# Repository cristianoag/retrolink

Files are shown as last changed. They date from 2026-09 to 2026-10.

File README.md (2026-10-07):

# The Retro Hacker RetroLink

RetroLink is an open-source hardware and firmware project for connecting controllers to classic MSX computers through the MSX DB9 General Purpose port. **RetroLink USB** connects USB HID joysticks and gamepads, or USB mice when flashed with the mouse firmware. **RetroLink MD** translates Mega Drive/Genesis 3-button and 6-button controller signals into MSX joystick signals. Both variants use an RP2040 Zero.

### RetroLink USB

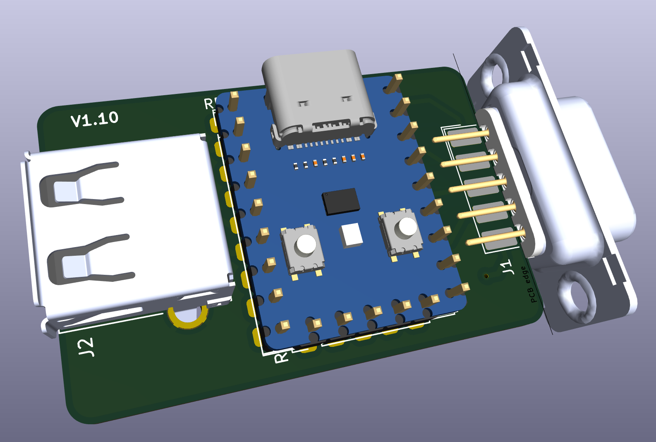
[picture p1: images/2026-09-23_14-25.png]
RetroLink USB hardware revision 1.10 angled 3D render with RP2040 Zero, USB-A connector, and DE9 socket


The latest RetroLink USB hardware revision, `1.10`, uses an RP2040 Zero module on a custom adapter board with:

- USB-A host connector for the USB HID device.
- DB9 connector for the MSX joystick/general purpose port.
- MSX DB9 pin 5 as the installed adapter power source.
- 1N5819 Schottky diode protection to prevent USB-C programming power from backfeeding the MSX.

### RetroLink MD

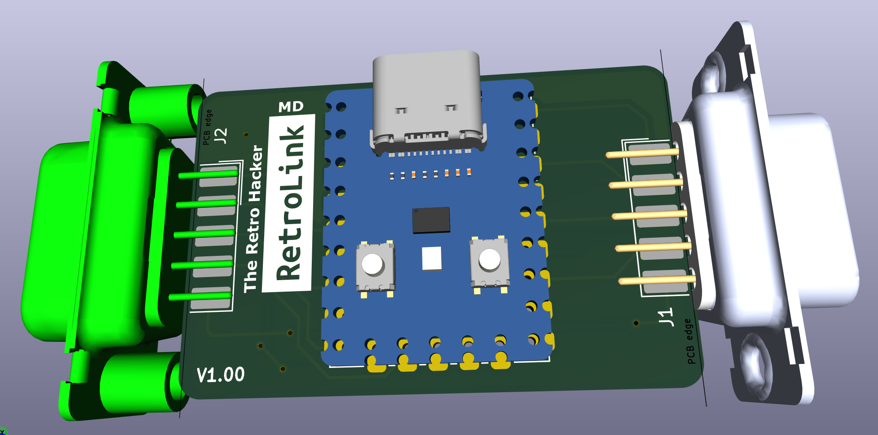
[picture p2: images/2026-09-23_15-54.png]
RetroLink MD revision 1.00 angled 3D render with RP2040 Zero and Mega Drive and MSX DE9 connectors


RetroLink MD hardware revision `1.10` replaces USB-A controller input with a **male DE9 for the Mega Drive controller**, retaining a **female DE9 for the MSX**. Its separate firmware maps MD B/C to MSX triggers A/B and reads the MSX common signal. 

## PCB Preview

### RetroLink USB revision 1.10

Top view of RetroLink USB hardware revision `1.10` (3D render):

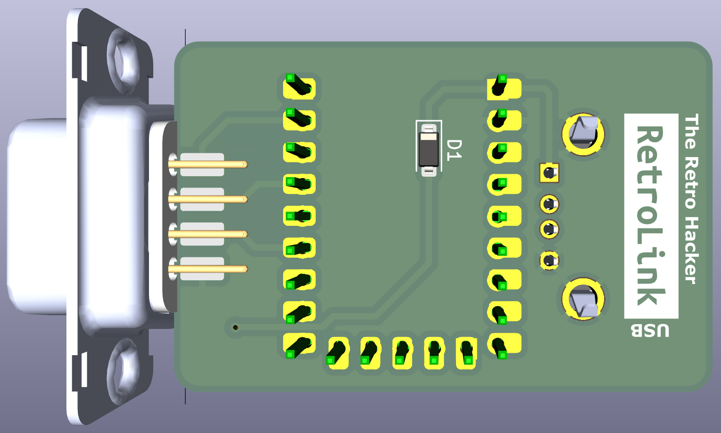
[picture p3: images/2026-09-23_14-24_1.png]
RetroLink USB revision 1.10 PCB top render with RP2040 Zero, USB-A connector, and DE9 socket


Bottom view of RetroLink USB hardware revision `1.10` (3D render):

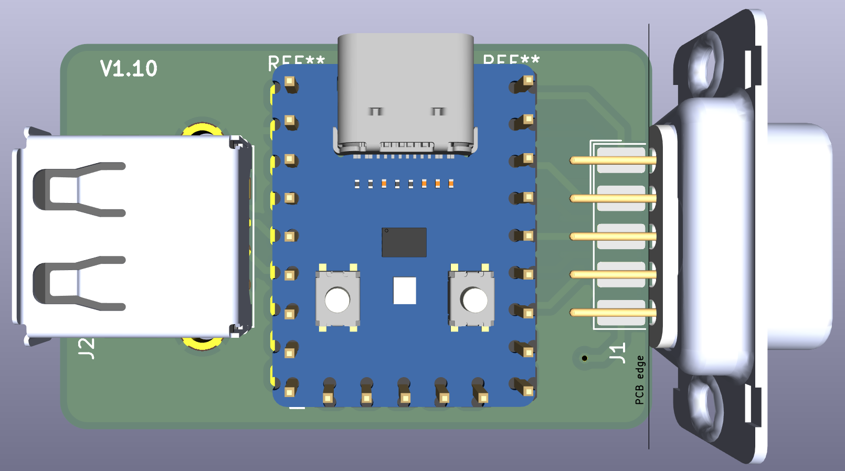
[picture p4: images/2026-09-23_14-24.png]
RetroLink USB revision 1.10 PCB bottom render showing the diode, connector pads, and RetroLink USB branding


### RetroLink MD revision 1.00

Front of the MD PCB (3D render):

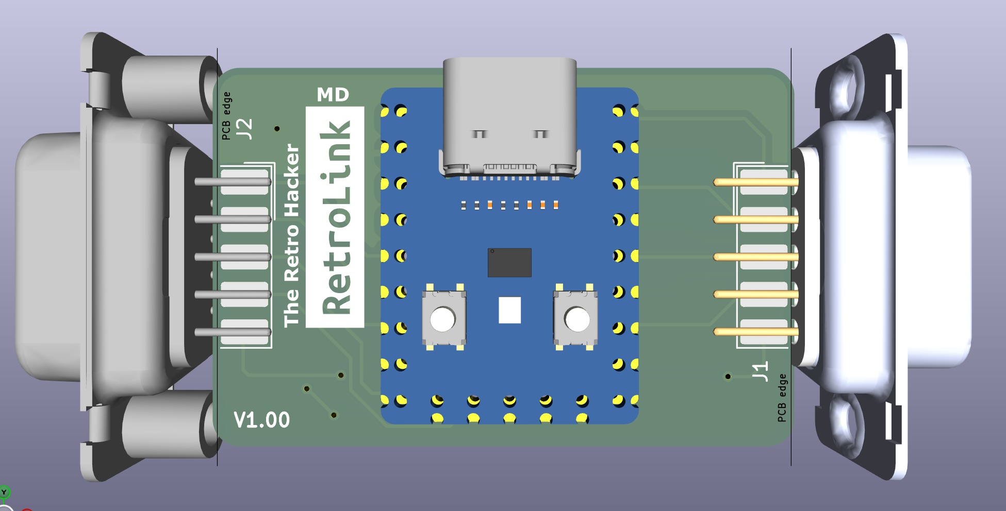
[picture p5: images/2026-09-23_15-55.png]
RetroLink MD revision 1.00 front render showing RP2040 Zero and both DE9 connectors


Back of the MD PCB (3D render):

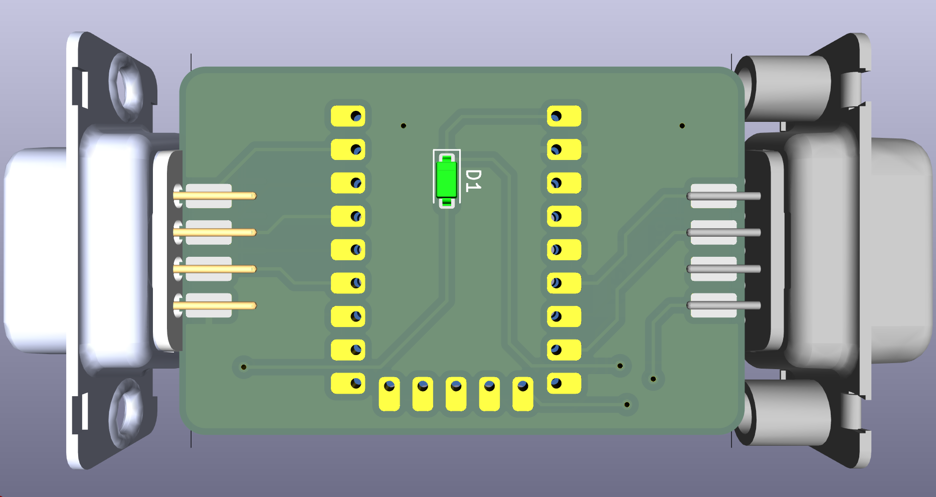
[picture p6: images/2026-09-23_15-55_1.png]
RetroLink MD revision 1.00 back render showing the diode, connector pads, and routing


## Variants and Versions

| Variant | Input | Hardware | Software and firmware |
| --- | --- | --- | --- |
| RetroLink USB | USB HID joystick/gamepad, or USB HID mouse | Latest: [revision `1.10`](hardware/usb/1.10); earlier revisions under [hardware/usb](hardware/usb) | [Joystick source](software/usb/joystick) (firmware `1.10`), [mouse source](software/usb/mouse) (firmware `1.00`), and [UF2 artifacts](firmware/usb) |
| RetroLink MD | Mega Drive/Genesis 3-/6-button controller | [Revision `1.10`](hardware/md/1.10) | [MD source](software/md) and [UF2 artifacts](firmware/md); firmware `1.10` |

The [USB specification](docs/specification.md) is version `1.00` and describes USB hardware revision `1.00`, not the MD variant. See the [MD wiring and behavior guide](software/md/README.md) for MD details and [docs/log.md](docs/log.md) for both variants' change log. Revisions are organized within each variant; a hardware directory does not imply a corresponding firmware release.

## Repository Layout

| Path | Purpose |
| --- | --- |
| [software/usb/joystick](software/usb/joystick) | USB joystick/gamepad firmware source using the Raspberry Pi Pico SDK, TinyUSB, and Pico-PIO-USB; also hosts sources shared with the mouse and MD builds. |
| [software/usb/mouse](software/usb/mouse) | USB mouse-to-MSX mouse firmware source for the same USB hardware. |
| [firmware/usb](firmware/usb) | USB joystick and mouse UF2 firmware artifacts. |
| [hardware/usb](hardware/usb) | USB KiCad project files by hardware revision. |
| [software/md](software/md), [firmware/md](firmware/md), [hardware/md](hardware/md) | MD controller-to-MSX source, generated UF2 firmware, and hardware revisions. |
| [images](images) | PCB preview renders used in this README. |
| [docs](docs) | Technical specification and version log. |
| [software/third_party/Pico-PIO-USB](software/third_party/Pico-PIO-USB) | Git submodule for GPIO-based USB host support on RP2040. |

## Firmware Build

### USB firmware

Initialize submodules after cloning:

```powershell
git submodule update --init --recursive
```

Build from the firmware source folder for the device you will connect:

```powershell
cd software\usb\joystick   # USB joysticks/gamepads
make
cd ..\mouse                # USB mice
make
```

Each build generates a versioned UF2 file for the same USB hardware:

```text
firmware/usb/retrolink-joystick-1.10.uf2
firmware/usb/retrolink-mouse-1.00.uf2
```

On Windows, the Makefile discovers Pico SDK-managed tools under `%USERPROFILE%\.pico-sdk`. Override `PICO_SDK_ROOT`, `PICO_SDK_PATH`, `PICO_TOOLCHAIN_PATH`, `CMAKE`, `CMAKE_MAKE_PROGRAM`, `PYTHON3_EXECUTABLE`, `PICOTOOL_DIR`, `PIOASM_DIR`, or `PICO_PIO_USB_PATH` if your toolchain is installed elsewhere.

### MD firmware

From the repository root, using the same Pico SDK toolchain:

```powershell
make -C software\md
```

Output: [firmware/md/retrolink-md-1.00.uf2](firmware/md/retrolink-md-1.00.uf2). The MD build does not use Pico-PIO-USB. See [MD build instructions and tests](software/md/README.md#build). Use the UF2 for the correct hardware variant.

## RetroLink MD Firmware Behavior

The controller data pins are **MD_UP=GPIO28, MD_BA=GPIO27, MD_DOWN=GPIO26, MD_THSEL=GPIO15, MD_LEFT=GPIO14, MD_CSTART=GPIO13, MD_RIGHT=GPIO12**. MSX up/A/down/B/left/common/right remain on GPIO0/1/2/3/4/5/6.

Firmware `1.10` reads standard 3- and 6-button pads, maps directions and B/C to the six MSX controls, and cancels opposing directions. A/Start/X/Y/Z/Mode are decoded but unmapped. Absent, invalid, or over-time frames release controls; reconnecting restores normal polling. GPIO5 monitors MSX OUT/common and releases all outputs when high. USB-C CDC provides diagnostics and GPIO16 LED pulses indicate newly asserted controls.

The MD [schematic](hardware/md/1.00/retrolink.kicad_sch), [PCB](hardware/md/1.00/retrolink.kicad_pcb), and [BOM](hardware/md/1.00/production/bom.csv) are available. MD pin 8 is ground, while MSX ground is pin 9 and MSX pin 8 is a driven signal. 

MD [revision `1.10`](hardware/md/1.10) also has a [dual-DB9 four-clip PLA case](hardware/md/1.10/case/README.md), measuring 54.19 x 33.50 x 19.70 mm after a 4 mm extension toward the male connector, with mirrored DB9 end profiles. Physical case fit and retention testing remain pending, particularly at the male end whose supplied 3D model is incorrect.

The MD build disables the RP2040 B0/B1 USB enumeration workaround because it takes over GPIO15 (MD SELECT); B2 silicon is preferred for USB-C diagnostics.

## RetroLink USB Joystick Firmware Behavior

USB joystick firmware version `1.10` (`retrolink-joystick-1.10.uf2`) decodes standard USB HID joystick/gamepad axes, hats, and buttons into six active-low MSX outputs: GPIO0/2/4/6 for up/down/left/right, GPIO1 for button A, and GPIO3 for button B. GPIO5 is reserved for the MSX OUT/strobe input, unused in joystick mode. Button usages 1 and 2 map to A and B. Outputs release to high impedance when inactive. The current source requires updated MSX wiring and USB-A D+/D- on GPIO27/28, not the original hardware revision `1.00` wiring. USB-C CDC provides diagnostics, and the RP2040 Zero status LED pulses on newly asserted controls. See [software/usb/joystick/README.md](software/usb/joystick/README.md#current-behavior) for supported layouts, decoder limits, and tests; physical controller/MSX validation remains required.

## RetroLink USB Mouse Firmware Behavior

USB mouse firmware version `1.00` (`retrolink-mouse-1.00.uf2`) runs on the same USB hardware revision `1.10`. It implements the MSX mouse protocol: each DB9 pin 8 (GPIO5) strobe edge places the next nibble of the signed X/Y movement on pins 1-4 (GPIO0/2/4/6). The left and right buttons drive pins 6/7 (GPIO1/3). A dedicated RP2040 core answers strobe edges in well under a microsecond. Boot-protocol and report-descriptor mice are supported, including report IDs and 12/16-bit axes. Holding the left button while connecting the mouse selects MSX-mouse-style joystick emulation. See [software/usb/mouse/README.md](software/usb/mouse/README.md#current-behavior) for protocol timing, scaling, limits, and tests; validation with a physical MSX remains required.

The current status LED implementation assumes the common RP2040 Zero onboard WS2812-compatible LED on GPIO 16. Validate this against the exact board variant before treating the build as hardware-final.

## RetroLink USB Hardware Status

The latest hardware revision, `1.10`, includes the KiCad project, schematic, PCB layout shown in the previews above, and updated BOM and production exports:

- [hardware/usb/1.10/retrolink.kicad_pro](hardware/usb/1.10/retrolink.kicad_pro)
- [hardware/usb/1.10/retrolink.kicad_sch](hardware/usb/1.10/retrolink.kicad_sch)
- [hardware/usb/1.10/retrolink.kicad_pcb](hardware/usb/1.10/retrolink.kicad_pcb)
- [The Retro Hacker RetroLink USB BOM (interactive, revision `1.10`)](hardware/usb/1.10/bom/ibom.html)
- [Exported component BOM](hardware/usb/1.10/production/bom.csv)
- [Production outputs](hardware/usb/1.10/production)
- [Compact four-clip PLA case: STLs, STEP and print instructions](hardware/usb/1.10/case/README.md) (reinforced short roots and padded DB9 rear support; physical strength and retention testing pending).

GitHub displays the iBOM HTML as a repository file, not an interactive page. Download the raw HTML or open the local file in a browser to use its component highlighting and assembly checklist.

## PCB Components

Quantities are per USB PCB, taken from the revision `1.10` [interactive BOM](hardware/usb/1.10/bom/ibom.html), dated 2026-09-23, and matching [production BOM](hardware/usb/1.10/production/bom.csv). AliExpress links are search placeholders, not verified product recommendations; replace them with selected listings after checking dimensions, pinout, package, and electrical ratings. Availability and seller quality have not been verified.

| Reference | Component / BOM value | Quantity | PCB footprint / selection notes | AliExpress |
| --- | --- | --- | --- | --- |
| RZ1 | RP2040 Zero module | 1 | `RP2040-Zero`; check module dimensions and pinout against the PCB. | [Search RP2040 Zero](https://www.aliexpress.com/w/wholesale-rp2040-zero.html) |
| J1 | DE9 female socket (`DE9_Socket`) | 1 | `DSUB-9_Socket_EdgeMount_P2.77mm`; edge-mount, 2.77 mm pitch. Verify contact gender and mounting geometry. | [Search DB9 female edge-mount](https://www.aliexpress.com/w/wholesale-db9-female-edge-mount.html) |
| J2 | USB-A receptacle (`USB_A`) | 1 | `TE_6364372-2`; verify signal pins, shell tabs, and mounting dimensions. | [Search USB-A PCB socket](https://www.aliexpress.com/w/wholesale-usb-type-a-female-pcb.html) |
| D1 | Schottky diode (`1N5819` BOM value) | 1 | `D_SOD-123`; the selected part must fit SOD-123. A common axial DO-41 1N5819 will not fit; confirm the exact SMD part, ratings, and polarity before ordering. | [Search 1N5819 SOD-123](https://www.aliexpress.com/w/wholesale-1n5819-sod-123.html) |

This table matches the revision `1.10` BOM exports; it does not establish electrical validation or a complete implementation of the specification's protection requirements. Use the iBOM for placement, and regenerate assembly outputs after hardware changes.

## License

This project is licensed under the [Creative Commons Attribution-NonCommercial-ShareAlike 4.0 International License](http://creativecommons.org/licenses/by-nc-sa/4.0/).

- You may remix and adapt the material with proper attribution.
- Derivative works must be shared under the same license.
- Commercial use is not permitted without explicit authorization.

See [LICENSE.txt](LICENSE.txt) for the full license text. Third-party components retain their respective licenses.

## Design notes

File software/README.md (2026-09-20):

# RetroLink Software

Firmware source code lives under this directory. Generated UF2 files are copied to `../firmware/` by the CMake build.

## Build

Prerequisites:

- Raspberry Pi Pico SDK available through `PICO_SDK_PATH`.
- A Pico SDK version that provides TinyUSB host support for RP2040 and, for hardware revision `1.00`, PIO USB host support on GPIO 2 and GPIO 3.
- Pico-PIO-USB providing `pio_usb.h` and the `pico_pio_usb` CMake target; the Makefile defaults to the repo submodule at `../third_party/Pico-PIO-USB`.
- CMake and an ARM GCC toolchain supported by the Pico SDK.

Build from this directory:

```powershell
make
```

On this development machine, the Makefile defaults to the Pico SDK-managed CMake, Ninja, Python, SDK, ARM GCC toolchain, picotool, and pioasm paths under `C:/Users/Cristiano/.pico-sdk`. Pico-PIO-USB is repo-managed under `../third_party/Pico-PIO-USB`. Override `CMAKE`, `CMAKE_MAKE_PROGRAM`, `PYTHON3_EXECUTABLE`, `PICO_SDK_PATH`, `PICO_TOOLCHAIN_PATH`, `PICOTOOL_DIR`, `PIOASM_DIR`, or `PICO_PIO_USB_PATH` on the `make` command line if another installation should be used.

After cloning the repository, initialize dependencies with:

```powershell
git submodule update --init --recursive
```

Or configure and build from the repository root:

```powershell
cmake -S software -B software/build -DPICO_SDK_PATH=$env:PICO_SDK_PATH
cmake --build software/build
```

The expected firmware artifact is:

```text
firmware/retrolink-1.00.uf2
```

The Makefile uses the same CMake target and keeps the firmware version in the UF2 file name.

## Current Behavior

Firmware version `1.00` initializes USB CDC debug on the RP2040 Zero USB-C port and TinyUSB host mode on the USB-A port through Pico-PIO-USB. Standard HID joystick/gamepad report descriptors determine the control locations; the first report is decoded immediately, not used as a neutral baseline.

| MSX control | GPIO | DB9 pin | USB HID control |
| --- | --- | --- | --- |
| Up | 6 | 1 | Low Y, hat up, or D-pad up |
| Down | 7 | 2 | High Y, hat down, or D-pad down |
| Left | 8 | 3 | Low X, hat left, or D-pad left |
| Right | 9 | 4 | High X, hat right, or D-pad right |
| Button A | 10 | 6 | Button usage 1 |
| Button B | 11 | 7 | Button usage 2 |

All outputs assert low and release to input/high impedance, with internal pull-ups disabled. The documented BSS138 level shifters and external pull-ups remain required; never connect 5 V MSX signals directly to RP2040 GPIOs. GPIO12 / DB9 pin 8 is not driven by this joystick implementation.

Absolute X/Y axes use the descriptor's logical range: below 25% asserts left/up, above 75% asserts right/down, and the middle 50% is neutral. Four-way and eight-way hats are supported, including diagonal combinations for eight-way hats; values outside the logical range are neutral. Axis and D-pad directions are combined. Opposing directions cancel each other. Button usage numbers may not match the controller's printed labels.

States are kept separately per report ID and interface and combined for the MSX port. Detach, truncated reports, and failed receive requests release the affected interface's contribution without releasing another controller's held controls. A failed receive request is logged; reconnect the controller to restart reception. Unknown report IDs leave the current state unchanged. The LED pulses on newly asserted decoded controls.

The decoder supports absolute variable fields in Joystick/Game Pad application collections, signed/unsigned fields up to 32 bits, and report IDs. It uses fixed limits: 32 mapped fields, 8 input report IDs, 512 input payload bits per report, 32 explicit local usages, 8 collection levels, and 4 global push levels. Oversized or unsupported descriptors are logged as `supported=0` and do not drive outputs. Array controls, relative axes, vendor-specific protocols, local delimiters, and long descriptor items are not supported; unsupported fields are ignored when other usable controls exist. Mouse emulation is not implemented. These limits and mappings have not yet been validated against the user's physical controller.

Use a serial terminal on the USB-C CDC device to monitor boot, host initialization, HID mount/unmount, descriptor mapping status, receive failures, and decoded state changes. The state byte uses bits 0 through 5 for up, down, left, right, A, and B respectively.

The status LED implementation assumes the common RP2040 Zero onboard WS2812-compatible LED on GPIO 16. If a board variant uses a different LED circuit, update `include/retrolink/board_config.h` before building.

## Module Interfaces

- `joystick_state_t` is a bitmask of the six `JOYSTICK_*` controls, independent of GPIO assignments.
- `hid_joystick_parse()` initializes a descriptor mapping and returns false with an empty mapping for unsupported or malformed descriptors.
- `hid_joystick_decode()` updates the matching report state and returns the combined state; false indicates an invalid report and clears all states for that interface. Unknown IDs are ignored successfully. Pass a parsed mapping and a non-null output state pointer.
- `msx_port_init()` releases all six GPIOs; `msx_port_set_state()` applies a complete logical state and cancels opposing directions. The trigger-A setter/getter remain available and preserve the other controls.

## Host Tests

After a firmware build has created `software/build`, run from the repository root with a native GCC compiler:

```powershell
gcc -std=c11 -Wall -Wextra -Werror -I software/include software/src/hid_joystick.c software/tests/hid_joystick_test.c -o software/build/hid_joystick_test.exe
./software/build/hid_joystick_test.exe
gcc -std=c11 -Wall -Wextra -Werror -I software/tests/stubs -I software/include software/src/msx_port.c software/tests/msx_port_test.c -o software/build/msx_port_test.exe
./software/build/msx_port_test.exe
```

Tests cover descriptor bounds, report IDs, axes, hats, buttons, GPIO assignments, high-impedance release, held-control continuity, and opposing directions. GPIO tests use a stub; they do not establish electrical or USB runtime correctness. On hardware, verify each direction and button, simultaneous controls, neutral release, and unplugging while controls are held.

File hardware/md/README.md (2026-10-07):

# RetroLink MD Hardware

RetroLink MD revision [1.00](1.00/) connects a Mega Drive controller's female DE9 plug to a male DE9 on the adapter; the adapter's female DE9 connects to the MSX. An RP2040 Zero translates the controller protocol into MSX joystick signals.

- [Schematic](1.00/retrolink.kicad_sch)
- [PCB](1.00/retrolink.kicad_pcb)
- [Project](1.00/retrolink.kicad_pro)
- [Exported BOM](1.00/production/bom.csv)
- [Renders](../../README.md#retrolink-md-revision-100)
- [Firmware, exact GPIO assignments, and electrical prerequisites](../../software/md/README.md)

MD D0/D1/D2/D3/D4/D5 use GPIO28/26/14/12/27/13; TH/SELECT uses GPIO15. MSX up/A/down/B/left/common/right use GPIO0/1/2/3/4/5/6. GPIO16 is the status LED. No USB-A host or MSX voltage-sense input is assigned in this variant.

USB hardware is maintained separately under [hardware/usb](../usb/).

Revision [1.10](1.10/) has a [compact four-clip PLA case](1.10/case/README.md)
for its two DB9 connectors, with STLs, STEP and a parametric generator. Its
54.19 x 33.50 x 19.70 mm plastic envelope is extended 4 mm toward the male DB9
relative to the original USB-sized design. The male end mirrors the female-end
profile instead of using the known incorrect male 3D model's through-passages.
USB-C programming requires opening the case. Physical fit,
clip durability and connector retention still require testing.

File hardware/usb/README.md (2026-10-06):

# RetroLink USB Hardware

KiCad hardware revisions for the USB HID-to-MSX variant live here. Revision `1.00` has the PCB and production exports documented in the [project README](../../README.md#retrolink-usb-hardware-status). Revision `1.10` is present as a separate revision directory; check its project files before using it for fabrication. The planned Mega Drive-to-MSX design belongs in [hardware/md](../md/), not here.

Revision `1.10` also has a [compact four-clip PLA case](1.10/case/README.md), with printable STLs, an editable STEP assembly, and a parametric generator. It exposes USB-A and DB9; opening the case is required for RP2040 Zero USB-C programming. Dedicated PCB end stops target 0.20 mm total nominal lengthwise play. Reinforced short clip roots and a padded metal-backshell cradle keep the DB9 flange outside. No screws or long latches are used; physical clip strength and frictional connector retention still require testing.

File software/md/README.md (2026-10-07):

# RetroLink MD Software

RP2040 Zero firmware `1.10` for RetroLink MD hardware revision `1.10`; its GPIO assignments also match revision `1.00`. It polls standard Mega Drive/Genesis 3-button and 6-button controllers and translates directions plus B/C into MSX joystick signals. This is a separate build from [RetroLink USB](../usb/README.md); do not flash a USB joystick or mouse UF2 onto the MD board.

## Wiring

### Mega Drive connector (male DE9)

| MD pin | Signal | GPIO | RP2040 direction |
| --- | --- | --- | --- |
| 1 | MD_UP / D0 | 28 | Input through 5 V-safe level conversion |
| 2 | MD_DOWN / D1 | 26 | Input through 5 V-safe level conversion |
| 3 | MD_LEFT / D2 | 14 | Input through 5 V-safe level conversion |
| 4 | MD_RIGHT / D3 | 12 | Input through 5 V-safe level conversion |
| 5 | Controller supply | None | Protected controller power rail |
| 6 | MD_BA / D4 | 27 | Input through 5 V-safe level conversion |
| 7 | MD_THSEL / SELECT | 15 | Output through noninverting 3.3 V-to-controller-voltage translation |
| 8 | GND | None | Board ground |
| 9 | MD_CSTART / D5 | 13 | Input through 5 V-safe level conversion |

### MSX connector (female DE9)

| MSX pin | Signal | GPIO | Behavior |
| --- | --- | --- | --- |
| 1 | Up | 0 | Active-low / high-impedance release |
| 2 | Down | 2 | Active-low / high-impedance release |
| 3 | Left | 4 | Active-low / high-impedance release |
| 4 | Right | 6 | Active-low / high-impedance release |
| 5 | MSX +5 V | None | Protected board power input |
| 6 | Trigger A | 1 | MD B |
| 7 | Trigger B | 3 | MD C |
| 8 | OUT / joystick common | 5 | Input; high releases all six outputs |
| 9 | GND | None | Board ground |

GPIO16 remains the onboard WS2812-compatible status LED. GPIO13 is **not** an MSX voltage-sense input in this variant. GPIO27/28 are **not** USB-A signals. UART stdio is disabled so GPIO0/1 remain available for MSX.

The SDK's USB enumeration workaround for older RP2040 B0/B1 chips temporarily takes over GPIO15. This build explicitly disables it with `TUD_OPT_RP2040_USB_DEVICE_ENUMERATION_FIX=0` to preserve MD SELECT. Prefer B2 silicon for USB-C diagnostics; on B0/B1 chips, enumeration through some USB hubs may fail without the workaround.

**Electrical prerequisites:** RP2040 pins are not 5 V tolerant. Provide 5 V-safe MD data inputs, a level-translated TH output, six MSX low/release interfaces, and a 5 V-safe MSX common input. Firmware assumes noninverting interfaces. Use external pull-ups on the MD connector side to define unplugged readings; the firmware also enables RP2040 input pull-ups. An LVC buffer's output pull-up alone does not define a floating buffer input. The four-component MD BOM does not include the required level-conversion/protection circuits.

MD pin 8 and MSX pin 9 are ground. **Do not ground MSX pin 8.** Validate connector orientation, the supply after the protection diode, MSX current budget, and USB-C backfeed protection before connecting either system. Renders and compiled firmware are not electrical validation.

## Behavior

- MD directions map directly; opposing directions cancel.
- MD B maps to MSX trigger A; MD C maps to MSX trigger B.
- A, Start, X, Y, Z, and Mode are decoded for diagnostics but do not activate MSX controls.
- GPIO15 idles high. Each poll performs four low/high TH cycles, with a 10 us settling delay after each transition. Samples are taken at idle high, first low, third low/high, and fourth low.
- A 3 ms initial high interval resets the pad protocol. The next poll is scheduled at least 5 ms after the previous poll and its diagnostics finish, preserving the reset interval even when software is delayed. A normal sampled frame takes approximately 80 us plus GPIO/software overhead.
- A frame exceeding 500 us is rejected rather than using potentially misaligned button data. Interrupts remain enabled during polling to service the MSX common input. The timing budget and settling delays must be validated on real pads, especially clones.
- Low-phase identification and the extended identification/end phases distinguish standard 3- and 6-button pads. Absent or invalid frames release controls on that poll; a later valid frame reconnects automatically. Master System pads, mice, multitaps, and vendor-specific extensions are not supported.
- MSX output latches remain zero; only GPIO direction changes. GPIO5 rise/fall interrupts release or restore the current held controls according to MSX common. This is software-interrupt-driven, not zero-latency hardware gating or MSX mouse emulation; validate common-to-output timing on the intended MSX.
- The LED pulses on newly asserted mapped controls.

Native USB-C CDC provides firmware identity, controller type, raw button bits, raw D0..D5 samples for each TH phase, the MSX pin 8 common level, mapped MSX state, connection/invalid-frame changes, and timing errors. Status prints on any decoded or common-level change, on raw-sample changes (at most every 100 ms), and once per second. It does not wait for a terminal at boot. Serial writes use zero host-buffer wait timeout; debug text can be dropped when the host is not reading, rather than waiting for buffer space. USB CDC reset commands are disabled; use the physical BOOT/RESET buttons for reflashing.

Diagnostic `buttons` bits 0..11 are Up, Down, Left, Right, B, C, A, Start, Z, Y, X, Mode. `raw` lists the idle-high, first-low, third-low, third-high, and fourth-low samples, with bits 0..5 = D0..D5 and 1 = high; with no pad, every sample reads `3f`, and an idle 3-button pad reads `3f/33/33/3f/33`. `common=1` means MSX pin 8 is high and all outputs are released. `MSX` bits 0..5 are Up, Down, Left, Right, trigger A, trigger B (the requested controls before common-line gating).

## Build

Prerequisites: Raspberry Pi Pico SDK with its TinyUSB submodule initialized, CMake, Ninja or a compatible generator, ARM GCC, Python, and the Pico SDK tools. Pico-PIO-USB is not used by this variant.

From the repository root:

```powershell
make -C software\md
```

The Makefile follows the USB project's Windows tool discovery under `%USERPROFILE%\.pico-sdk`. Override `PICO_SDK_ROOT`, `PICO_SDK_PATH`, `PICO_TOOLCHAIN_PATH`, `CMAKE`, `CMAKE_MAKE_PROGRAM`, `PYTHON3_EXECUTABLE`, `PICOTOOL_DIR`, or `PIOASM_DIR` when necessary.

Output: [firmware/md/retrolink-md-1.10.uf2](../../firmware/md/retrolink-md-1.10.uf2). The Makefile's `FIRMWARE_VERSION` is passed to CMake (default in `CMakeLists.txt`) so the UF2 name and reported version match; hardware assignments and polling timings live in `include/retrolink/board_config.h`.

The target reuses the USB joystick project's (`../usb/joystick`) `joystick.h`, `status_led.h`, `status_led.c`, and `ws2812.pio`. Its own include directory comes first, so the shared LED driver uses the MD board configuration. MD protocol and MSX common-line handling are separate modules; no USB host code is linked.

`md_port_poll()` requires a non-null output state and at least the configured TH-high reset interval between calls. It always ends with TH high and returns an explicit poll result; the main loop logs absent/invalid or timing-error status and releases MSX controls. `md_pad_decode()` operates on packed D0..D5 samples; `md_pad_to_msx()` maps B/C and cancels opposing directions.

## Tests

Native CMake test mode is available with `RETROLINK_HOST_TESTS=ON`; use a separate `build-tests` directory and a native C compiler, not ARM GCC. Build and run `md_pad_test` and `md_io_test` through CMake Tools/CTest.

Alternatively, after creating `software/md/build`, run the native GCC tests from the repository root:

```powershell
gcc -std=c11 -Wall -Wextra -Werror -I software\md\include -I software\usb\joystick\include software\md\src\md_pad.c software\md\tests\md_pad_test.c -o software\md\build\md_pad_test.exe
.\software\md\build\md_pad_test.exe
gcc -std=c11 -Wall -Wextra -Werror -I software\md\tests\stubs -I software\md\include -I software\usb\joystick\include software\md\src\md_pad.c software\md\src\md_port.c software\md\src\msx_output.c software\md\tests\md_io_test.c -o software\md\build\md_io_test.exe
.\software\md\build\md_io_test.exe
```

For MSYS2 UCRT64 GCC on Windows, ensure its `bin` directory is on `PATH` for both compilation and execution.

Tests cover all 256 three-button and 4096 six-button states, exact pin assignments/uniqueness, B/C mapping, unmapped buttons, opposing directions, invalid frames, SELECT sequencing and settling, the 500 us timeout boundary, timer wraparound, detach/reconnect, high-impedance release, and common-line changes during polling. GPIO tests use a stub, not physical hardware.

Before use, measure voltage levels and TH/common timing, then test directions, diagonals, B/C, held controls, common-line toggles, unplug/replug, three- and six-button controllers, and operation without a USB-C terminal.

Protocol references: [3-button behavior](https://www.raspberryfield.life/2019/02/15/sega-mega-drive-genesis-3-button-abc-controller/) and [6-button sequence](https://www.raspberryfield.life/2019/03/25/sega-mega-drive-genesis-6-button-xyz-controller/).

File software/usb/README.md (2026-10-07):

# RetroLink USB Software

Firmware for the RetroLink USB board (USB-A host to MSX DB9). Both builds target the same hardware; flash the UF2 that matches the device you want to connect.

| Directory | Firmware | UF2 artifact |
| --- | --- | --- |
| [joystick](joystick/README.md) | USB HID joysticks and gamepads mapped to MSX joystick signals | `firmware/usb/retrolink-joystick-<version>.uf2` |
| [mouse](mouse/README.md) | USB HID mice mapped to the MSX mouse protocol, with optional joystick emulation | `firmware/usb/retrolink-mouse-<version>.uf2` |

Build either one with `make` from its directory, for example `make -C software/usb/mouse`. The mouse build and the [MD firmware](../md/README.md) reuse shared LED, CDC debug, and USB descriptor sources from `joystick/`.

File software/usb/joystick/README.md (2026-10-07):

# RetroLink USB Joystick Firmware

USB joystick/gamepad firmware source code lives under this directory. Generated UF2 files are copied to `../../../firmware/usb/` by the CMake build. The USB mouse firmware for the same hardware is in [`../mouse/`](../mouse/README.md), and the MD variant is in [`../../md/`](../../md/README.md). The mouse and MD builds reuse this directory's shared LED, CDC debug, USB descriptor, and `joystick.h` sources.

## Build

Prerequisites:

- Raspberry Pi Pico SDK available through `PICO_SDK_PATH`.
- A Pico SDK version that provides TinyUSB host support for RP2040 and PIO USB host support on GPIO 27 and GPIO 28.
- Pico-PIO-USB providing `pio_usb.h` and the `pico_pio_usb` CMake target; the Makefile defaults to the repo submodule at `../../third_party/Pico-PIO-USB`.
- CMake and an ARM GCC toolchain supported by the Pico SDK.

Build from this directory:

```powershell
make
```

On Windows, the Makefile discovers the Pico SDK-managed tools and SDK under `%USERPROFILE%\.pico-sdk` (or the `PICO_SDK_ROOT` override), without depending on a particular account name or installed version. If managed Python is not present, CMake searches for Python on `PATH`. Pico-PIO-USB is repo-managed under `../../third_party/Pico-PIO-USB`. Override `PICO_SDK_ROOT`, `CMAKE`, `CMAKE_MAKE_PROGRAM`, `PYTHON3_EXECUTABLE`, `PICO_SDK_PATH`, `PICO_TOOLCHAIN_PATH`, `PICOTOOL_DIR`, `PIOASM_DIR`, or `PICO_PIO_USB_PATH` on the `make` command line if your installation differs.

After cloning the repository, initialize dependencies with:

```powershell
git submodule update --init --recursive
```

Or configure and build from the repository root:

```powershell
cmake -S software/usb/joystick -B software/usb/joystick/build -DPICO_SDK_PATH=$env:PICO_SDK_PATH
cmake --build software/usb/joystick/build
```

The expected firmware artifact is:

```text
firmware/usb/retrolink-joystick-1.10.uf2
```

The Makefile passes `FIRMWARE_VERSION` to CMake, so the UF2 file name and the firmware's reported version stay in sync. Joystick UF2 files use the `retrolink-joystick-<version>.uf2` name; releases `1.00` and `1.10` were renamed from `retrolink-<version>.uf2` without changing their contents.

## Current Behavior

Firmware version `1.10` initializes USB CDC debug on the RP2040 Zero USB-C port and TinyUSB host mode on the USB-A port through Pico-PIO-USB. Standard HID joystick/gamepad report descriptors determine the control locations; the first report is decoded immediately, not used as a neutral baseline.

The current build uses GPIO27 for USB-A D+ and GPIO28 for D-. This consecutive pair satisfies Pico-PIO-USB's DPDM pinout and does not overlap the MSX or status LED assignments. USB-C uses the native USB controller and is unaffected. GPIO27/28 must not also be used as ADC inputs or for other peripherals.

This build matches the GPIO assignments of USB hardware revision `1.10`; it is not compatible with the original hardware revision `1.00` pin assignments documented in the [specification](../../docs/specification.md). Verify the actual board wiring, USB enumeration, and each MSX control on hardware before use.

| MSX control | GPIO | DB9 pin | USB HID control |
| --- | --- | --- | --- |
| Up | 0 | 1 | Low Y, hat up, or D-pad up |
| Down | 2 | 2 | High Y, hat down, or D-pad down |
| Left | 4 | 3 | Low X, hat left, or D-pad left |
| Right | 6 | 4 | High X, hat right, or D-pad right |
| Button A | 1 | 6 | Button usage 1 |
| Button B | 3 | 7 | Button usage 2 |
| OUT / strobe (input from MSX) | 5 | 8 | Not used in joystick mode |

All six control outputs assert low and release to input/high impedance, with internal pull-ups disabled. The documented BSS138 level shifters and external pull-ups remain required; never connect 5 V MSX signals directly to RP2040 GPIOs. GPIO5 / DB9 pin 8 is reserved as an input from the MSX and is neither initialized, read, nor driven by this joystick implementation.

The unused USB VBUS enable/fault reservations on GPIO4/5 have been removed; the updated board must not connect VBUS control/fault circuitry to these pins. UART stdio remains disabled, leaving GPIO0/1 available for MSX signals. Do not enable UART or other peripheral functions on GPIO0-6 while using this mapping.

Absolute X/Y axes use the descriptor's logical range: below 25% asserts left/up, above 75% asserts right/down, and the middle 50% is neutral. Four-way and eight-way hats are supported, including diagonal combinations for eight-way hats; values outside the logical range are neutral. Axis and D-pad directions are combined. Opposing directions cancel each other. Button usage numbers may not match the controller's printed labels.

States are kept separately per report ID and interface and combined for the MSX port. Detach, truncated reports, and failed receive requests release the affected interface's contribution without releasing another controller's held controls. A failed receive request is logged; reconnect the controller to restart reception. Unknown report IDs leave the current state unchanged. The LED pulses on newly asserted decoded controls.

The decoder supports absolute variable fields in Joystick/Game Pad application collections, signed/unsigned fields up to 32 bits, and report IDs. It uses fixed limits: 32 mapped fields, 8 input report IDs, 512 input payload bits per report, 32 explicit local usages, 8 collection levels, and 4 global push levels. Oversized or unsupported descriptors are logged as `supported=0` and do not drive outputs. Array controls, relative axes, vendor-specific protocols, local delimiters, and long descriptor items are not supported; unsupported fields are ignored when other usable controls exist. USB mice are handled by the separate [mouse firmware](../mouse/README.md). These limits and mappings have not yet been validated against the user's physical controller.

Use a serial terminal on the USB-C CDC device to monitor boot, host initialization, HID mount/unmount, descriptor mapping status, receive failures, and decoded state changes. The state byte uses bits 0 through 5 for up, down, left, right, A, and B respectively.

The status LED implementation assumes the common RP2040 Zero onboard WS2812-compatible LED on GPIO 16. If a board variant uses a different LED circuit, update `include/retrolink/board_config.h` before building.

## Module Interfaces

- `joystick_state_t` is a bitmask of the six `JOYSTICK_*` controls, independent of GPIO assignments.
- `hid_joystick_parse()` initializes a descriptor mapping and returns false with an empty mapping for unsupported or malformed descriptors.
- `hid_joystick_decode()` updates the matching report state and returns the combined state; false indicates an invalid report and clears all states for that interface. Unknown IDs are ignored successfully. Pass a parsed mapping and a non-null output state pointer.
- `msx_port_init()` releases all six GPIOs; `msx_port_set_state()` applies a complete logical state and cancels opposing directions. The trigger-A setter/getter remain available and preserve the other controls.

## Host Tests

After a firmware build has created `software/usb/joystick/build`, run from the repository root with a native GCC compiler:

```powershell
gcc -std=c11 -Wall -Wextra -Werror -I software/usb/joystick/include software/usb/joystick/src/hid_joystick.c software/usb/joystick/tests/hid_joystick_test.c -o software/usb/joystick/build/hid_joystick_test.exe
./software/usb/joystick/build/hid_joystick_test.exe
gcc -std=c11 -Wall -Wextra -Werror -I software/usb/joystick/tests/stubs -I software/usb/joystick/include software/usb/joystick/src/msx_port.c software/usb/joystick/tests/msx_port_test.c -o software/usb/joystick/build/msx_port_test.exe
./software/usb/joystick/build/msx_port_test.exe
```

Tests cover descriptor bounds, report IDs, axes, hats, buttons, the exact GPIO assignments, high-impedance release, held-control continuity, and opposing directions. GPIO tests also verify that OUT/strobe and unrelated pins remain untouched. GPIO tests use a stub; they do not establish electrical or USB runtime correctness. On hardware, verify each direction and button, simultaneous controls, neutral release, and unplugging while controls are held.

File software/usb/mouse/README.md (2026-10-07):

# RetroLink USB Mouse Firmware

Firmware for the **same RetroLink USB board** as the [joystick firmware](../joystick/README.md) (hardware revision `1.10`, RP2040 Zero). It turns a USB HID mouse on the USB-A port into an MSX-compatible mouse on the DB9 connector. Flash either the joystick UF2 or the mouse UF2; the firmware decides how the board behaves, and the PCB is not modified.

The build reuses the joystick directory's `debug_cdc.c`, `status_led.c`, `usb_descriptors.c`, `ws2812.pio`, `tusb_config.h`, and `joystick.h`. This directory's `include/` comes first, so those shared sources use the mouse `board_config.h`.

## Build

Prerequisites and tool overrides are the same as the [joystick build](../joystick/README.md#build). From this directory:

```powershell
make
```

Or from the repository root:

```powershell
make -C software/usb/mouse
```

The expected firmware artifact is:

```text
firmware/usb/retrolink-mouse-1.00.uf2
```

The Makefile passes `FIRMWARE_VERSION` to CMake, so the UF2 file name (`retrolink-mouse-<version>.uf2`) and the version reported over CDC stay in sync. Mouse firmware versions are independent of the joystick firmware versions.

## Current Behavior

Mouse firmware version `1.00` uses the joystick firmware's GPIO assignments, USB-A host pins (GPIO27 D+, GPIO28 D-), USB-C CDC debug port, and GPIO16 status LED.

| MSX mouse signal | GPIO | DB9 pin | Source |
| --- | --- | --- | --- |
| Data bit 0 | 0 | 1 | Current nibble bit 0 |
| Data bit 1 | 2 | 2 | Current nibble bit 1 |
| Data bit 2 | 4 | 3 | Current nibble bit 2 |
| Data bit 3 | 6 | 4 | Current nibble bit 3 |
| Left button | 1 | 6 | USB button 1 (left) |
| Right button | 3 | 7 | USB button 2 (right) |
| Strobe (input from MSX) | 5 | 8 | Read by the firmware |

As in the joystick firmware, all six outputs pull low or release to high impedance. Internal pull-ups are disabled. A nibble bit of `0` pulls its line low, and a `1` releases it. GPIO5 is a high-impedance input with internal pulls disabled and depends on the board's BSS138 level shifter and pull-ups. Never connect 5 V MSX signals directly to RP2040 GPIOs.

### MSX mouse protocol

Each change on DB9 pin 8 selects the next 4-bit nibble on pins 1-4:

| Pin 8 edge | Nibble presented |
| --- | --- |
| Rising (first after idle) | X offset bits 7-4 |
| Falling | X offset bits 3-0 |
| Rising | Y offset bits 7-4 |
| Falling | Y offset bits 3-0 |

Offsets are signed 8-bit values with the MSX sign convention: positive X means the mouse moved left, and positive Y means it moved up. USB HID uses the opposite signs, so the firmware inverts them. Each read sends at most ±127. Any larger movement carries over to later reads (backlog limited to ±1024 counts).

The MSX BIOS reads two complete sequences per scan, using the second to tell a mouse from a trackball. The firmware returns the movement in the first sequence and zero in the second, so the BIOS detects a mouse. If no strobe edge occurs for more than 1.5 ms (`RETROLINK_MOUSE_STROBE_TIMEOUT_US`), the sequence restarts. The next rising edge then sends newly accumulated movement. These timings follow the openMSX mouse emulation; they have not yet been measured against a physical MSX mouse.

Core 1 runs a dedicated loop from RAM. It polls GPIO5 and updates the outputs within well under a microsecond, independent of USB host activity on core 0. Core 0 runs TinyUSB, decodes reports, and sends the movement, buttons, and mode to core 1.

### USB mouse support

- Boot-protocol mice: TinyUSB puts boot-subclass mouse interfaces in boot protocol, so the fixed format (buttons, signed 8-bit X, signed 8-bit Y) is used.
- Report-protocol mice: other interfaces are decoded from their report descriptor. The decoder looks for relative X/Y and buttons 1-3 in Generic Desktop Mouse application collections. It supports report IDs and signed or unsigned fields up to 32 bits, such as the 12- or 16-bit axes used by wireless receivers.
- Boot keyboards, absolute-position pointers, joysticks, and descriptors without relative X/Y are ignored. Reports with unknown IDs, such as consumer controls, are skipped.
- USB movement is divided by `RETROLINK_MOUSE_DIVISOR` (default `2`), keeping the remainder so slow movement is not lost. Increase the divisor to slow the pointer or set it to `1` for full speed. The wheel and the middle button are not used.
- Buttons from multiple mice are combined. Movement from all mice is added together.

While no supported mouse is mounted, all DB9 outputs are released (the MSX sees no device). After a mouse mounts, the port answers the mouse protocol. It drives all four data lines low until the first strobe sequence. The LED pulses on movement and on newly pressed buttons.

### Joystick emulation

Like an original MSX mouse, the adapter can act as a joystick. To select joystick mode, hold the **left button** while plugging in the mouse, or while powering on the MSX with the mouse connected. If the first report within 1 s after mounting shows the left button pressed, joystick mode stays on until every mouse is removed. In this mode, the strobe is ignored. Movement is sampled every 20 ms and converted to up to eight directions on pins 1-4. A move needs at least 2 scaled counts on an axis to register. Left and right buttons drive triggers A and B. Some mice do not send a report until the button state changes, so this selection still needs testing on real mice.

### Diagnostics

Open the USB-C CDC port to see boot information, HID mount/unmount messages, `HID mouse mapping` support status, the selected mode (`released`, `MSX mouse`, `joystick emulation`), button changes, and receive failures. Movement is not logged.

## Module Interfaces

- `hid_mouse_parse()` builds a report layout from a descriptor; `hid_mouse_init_boot()` selects the boot layout. `hid_mouse_decode()` returns `OK`, `IGNORED` (unknown report ID or no mapped controls), or `INVALID` (null or truncated report).
- `msx_mouse_*` is the hardware-independent protocol: strobe-phase state machine, nibble/line conversion, movement scaling, joystick-emulation directions, and button mapping.
- `mouse_port_*` owns the GPIOs and the core 1 loop. Core 0 sets the mode, buttons, joystick directions, and movement.

## Host Tests

After a firmware build has created `software/usb/mouse/build`, run from the repository root with a native GCC compiler (for MSYS2 UCRT64, put its `bin` directory on `PATH`):

```powershell
gcc -std=c11 -Wall -Wextra -Werror -UNDEBUG -I software/usb/mouse/include -I software/usb/joystick/include software/usb/mouse/src/hid_mouse.c software/usb/mouse/tests/hid_mouse_test.c -o software/usb/mouse/build/hid_mouse_test.exe
./software/usb/mouse/build/hid_mouse_test.exe
gcc -std=c11 -Wall -Wextra -Werror -UNDEBUG -I software/usb/mouse/include -I software/usb/joystick/include software/usb/mouse/src/msx_mouse.c software/usb/mouse/tests/msx_mouse_test.c -o software/usb/mouse/build/msx_mouse_test.exe
./software/usb/mouse/build/msx_mouse_test.exe
```

The tests cover:

- Boot, basic, and report-ID descriptors with 12-bit axes, and unsupported or truncated descriptors.
- The BIOS strobe sequence, the zeroed alternate cycle, the nibble-to-pin mapping, ±127 clamping with carry, timeout resynchronization, and timer wraparound.
- Scaling remainders, the joystick-emulation directions, and the button mapping.

The core 1 GPIO loop is not covered by host tests. On hardware, test:

- Pointer direction in MSX-BIOS software and MSX-DOS2 tools.
- Both buttons, slow and fast movement, and the 1.5 ms timeout.
- Joystick-emulation selection.
- Unplug/replug.
- BSS138 rise times on pins 1-4 and 8.

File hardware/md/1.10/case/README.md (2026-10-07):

# RetroLink MD 1.10 compact four-clip case

Two-piece PLA enclosure for the [MD revision 1.10 PCB](../retrolink.kicad_pcb),
with a **male DB9 for the Mega Drive controller** and a **female DB9 for the MSX**.
The plastic envelope is **54.19 x 33.50 x 19.70 mm**: 4 mm longer toward the male
connector than the original MD case. Width and height still match the
[USB 1.10 case](../../../usb/1.10/case/README.md). The female end, PCB and clips
stay in their previous assembly positions.

Four short internal clips, alignment keys, over-travel stops and tight PCB end
stops carry over from USB. There are **no screws or long latches**. USB-C is
enclosed: open the case and lift the PCB as needed for programming.

**Prototype, not physically print-tested or load-rated.** Digital fit checks do
not establish clip durability, connector retention force or compatibility with
every real cable/port housing. Test one complete pair before use on equipment.

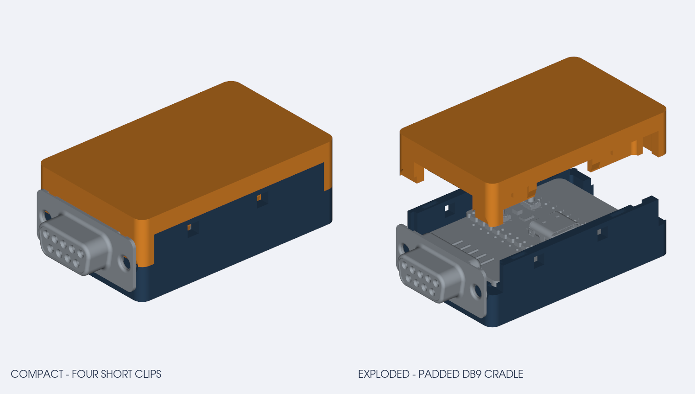
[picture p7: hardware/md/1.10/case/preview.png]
MD enclosure, assembled and exploded


## Print files

| File | Purpose |
| --- | --- |
| [Base STL](retrolink-md-1.10-base.stl) | MD bottom half, oriented with its outside face on the print bed. |
| [Lid STL](retrolink-md-1.10-lid.stl) | MD top half, oriented with its outside face on the print bed. |
| [Case STEP](retrolink-md-1.10-case.step) | Two assembled plastic solids for CAD editing. |
| [Generator](md_case.py) | MD connector openings, assembly checks and CLI. |
| [Tests](test_md_case.py) | Twelve MD geometry regressions, including one-sided extension and mirrored end profiles. |
| [Dependencies](requirements.txt) | Reuses the USB enclosure's pinned CAD dependencies. |

Dimensions are in **millimetres**. Slice at **100% scale**. Use both MD parts
together; reprint both halves for this revision. USB and MD halves are not
interchangeable. The preview includes electronics and female-end rubber pads,
but deliberately omits the known incorrect male connector model. STL and STEP
exports contain only the plastic case.

## Geometry and connector access

| Feature | Default |
| --- | --- |
| Plastic envelope, excluding exposed connectors | **54.19 x 33.50 x 19.70 mm** |
| PCB | 43 x 28 x 1.6 mm; 2 mm corner radius |
| Shell wall / roof / floor | 2.4 mm, except local pad recesses |
| Individual clip lengths, including roots | 14.7 / 14.1 mm |
| Clip beams / root radius | 1.2 x 4.8 mm / 1.2 mm in the bending plane |
| Clip engagement | 0.20 mm nominal |
| PCB lengthwise allowance | 0.10 mm per end, **0.20 mm total nominal travel** |
| Alignment-key clearance | 0.15 mm per mating face |
| Male DB9 rear-shell opening | 20.4 mm wide x 11.9 mm high, mirrored from the female end |
| Female DB9 rear-shell opening | 20.4 mm wide x 11.9 mm high |
| Programming opening | None; USB-C remains internal |

The male end now uses a mirrored copy of the female end's opening, shallow
mounting reliefs, pad recesses, wall thickness and low split seam. The old
male-specific circular through-passages are removed. The two end profiles are
checked for matching geometry, not merely equal opening dimensions.

This change follows the reported error in the supplied male connector model.
The female flange remains exposed as before. The actual male flange and plug
clearance must be verified on the real connector before use; the incorrect
model is not evidence of fit for the replacement profile.

The main PCB matches the USB outline, but the RP2040 Zero sits **2.835 mm farther
toward the male DB9**. Its adjacent clip over-travel stops are repositioned to
avoid the module substrate. Board end stops and PCB supports remain in place;
the extension does not add PCB travel or move the electronics.

### Size excludes protruding connectors

The 54.19 mm dimension measures only the plastic, from x=-6.75 to x=47.44 mm
in PCB coordinates. Do not use the known incorrect male model to infer the
finished adapter's tip-to-tip length.

## Connector support and rubber pads

The female **MSX end** retains the USB design's padded metal-backshell cradle.
Fit **two soft nonconductive rubber or silicone strips, 2 x 12 x 1 mm each**:

- Place one under and one above the female connector's rear flat metal shell.
- Use approximately Shore A 20-30 material. Do not substitute hard shims.
- Nominal pad compression is 0.20 mm each; each contact land is 24 mm2.
- Keep pad plus adhesive thickness at 1 mm. Start with a dry fit without pads,
  then check that adding them does not make closing force excessive.

The intended MSX extraction load path is case -> pad friction -> metal shell.
This is **not positive flange capture**. If the pads slip, the PCB and solder
joints can still carry extraction force. Tight PCB end stops do not replace
connector strain relief.

The mirrored male end includes matching pad recesses, but **male-end pad fit,
compression and grip are not validated**, because its model is incorrect.
Do not install pads there without measuring the actual metal contact lands.
Do not stuff pads around pins. Hold the exposed connector shell when
disconnecting a tight controller plug; do not use the case as a lever.
Grip and cycle-life testing remain necessary on both ends.

## Printing and assembly

Use PLA with a 0.4 mm nozzle and 0.20 mm layers as a starting point:

- Four perimeters, five top/bottom layers and 25-35% infill.
- Keep the supplied print orientations so the short arms run along layers.
- **Local supports are needed under all four horizontal clip arms.** Permit
  supports to start on part surfaces, not only on the print bed; inspect the
  slicer preview. Start with a removable 0.20 mm support-interface gap.
- The approximately 3.1 mm receiver windows should normally bridge, but check
  your printer's capability. Remove supports without bending clips outward.
- Prefer ordinary PLA, not brittle silk/filled blends. Avoid hot environments.

1. Disconnect all cables. Dry-fit the empty halves and verify gentle engagement
   of all four hooks before installing the board.
2. Lower the PCB onto its four support lands, male DB9 at one end and female at
   the other. Check the real male connector against the revised opening before
   closing; do not press on the pins or diode.
3. Fit the two rubber strips at the female MSX end after the unpadded fit is
   satisfactory. Align the stepped ends and alignment keys, then press near each
   clip. Stop if anything binds or a pad holds the seam open.
4. Check all four receiver windows and test plug clearance on unpowered spare
   connectors. Test that the female metal shell does not slide within the case
   under a gentle disconnected hand load.
5. Open by pressing each hook inward through its window with a blunt plastic
   tool and lifting that corner only enough to release it. Do not lever against
   still-engaged hooks or force a clip beyond its internal stop.

The clips are intended for occasional servicing, not repeated flexing.

## Regeneration

The MD source imports shared primitives, short clips, print orientations and
export validation from [the USB generator](../../../usb/1.10/case/case.py).
Keep that folder at its repository-relative location when regenerating; it is
not needed just to print the supplied STLs. This avoids maintaining two diverging
versions of the same clip design.

Python 3.13 was used. From this folder in PowerShell:

```powershell
python -m venv .venv
.\.venv\Scripts\python.exe -m pip install -r requirements.txt
.\.venv\Scripts\python.exe md_case.py
.\.venv\Scripts\python.exe -m unittest discover -s . -p test_md_case.py -v
```

The MD CLI keeps the exterior dimensions fixed. Available fit adjustments:

| Option | Supported range |
| --- | --- |
| `--board-end-clearance` | 0.05-0.20 mm per end |
| `--key-clearance` | 0.12-0.25 mm |
| `--hook-engagement` | 0.15-0.25 mm; lower values reduce both closing force and retention |
| `--pad-compression` | 0.10-0.20 mm per female-end rubber pad |

Use `--output .\trial` for alternative exports without replacing the defaults.
Changes to module mounting height, connector models or outside dimensions need
a new CAD fit review; the MD CLI deliberately does not expose size-changing
parameters.

For component checks excluding the known incorrect male model, export MD 1.10
with KiCad 10:

```powershell
$assembly = Join-Path $env:TEMP 'retrolink-md-1.10-fit.step'
& 'C:\Program Files\KiCad\10.0\bin\kicad-cli.exe' pcb export step `
    --force --user-origin '102.15x102.25mm' --output $assembly ..\retrolink.kicad_pcb
.\.venv\Scripts\python.exe md_case.py --assembly $assembly
Remove-Item $assembly
```

The local origin is the PCB lower-left corner, z=0 at its underside; +X points
toward the female DB9 and +Y toward the internal USB-C socket.

The generator requires the expected original assembly bounds, identifies the
known incorrect male solid by its bounds and volume, and prints an explicit
warning before excluding it from checks and the preview. It fails if the
signature is not recognized. No PCB or component source model is modified.
When a corrected male model becomes available, update this validation path
rather than continuing to exclude it.

Validation covers:

- A 4 mm male-only extension, unchanged width/height, four clips and 0.20 mm PCB travel.
- No nominal PCB, half-to-half or remaining MD component overlap.
- Board and lid insertion at twelve sampled heights, excluding the male connector.
- Mirrored end profiles, removed through-passages and a closed USB-C side.
- Shifted-module clearance, solder keepouts, clip release and over-travel stops.
- Two female-end pad lands contacting only the metal backshell.
- Connected, watertight print meshes at bed z=0 and a two-solid STEP round-trip.
- Twelve MD tests plus thirteen USB regression tests.

These are geometric checks, not a slicer simulation, material deformation model,
mechanical load test or electrical validation.

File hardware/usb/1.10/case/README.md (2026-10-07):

# RetroLink USB 1.10 compact four-clip case

Two printable PLA halves, **four short internal clips**, and the original compact
outline. No screws, nuts, long side latches or PCB drilling. USB-A and DB9 remain
accessible. The USB-C side opening is closed; open the case and lift the PCB as
needed to connect the RP2040 Zero's programming cable.

The first prototype was reported to break at the clip roots during closing.
This redesign addresses the root geometry and required deflection, but **has not
been physically print-tested**. Neither clip strength nor DB9 holding force is
load-rated. Print and test one pair before using it on equipment.

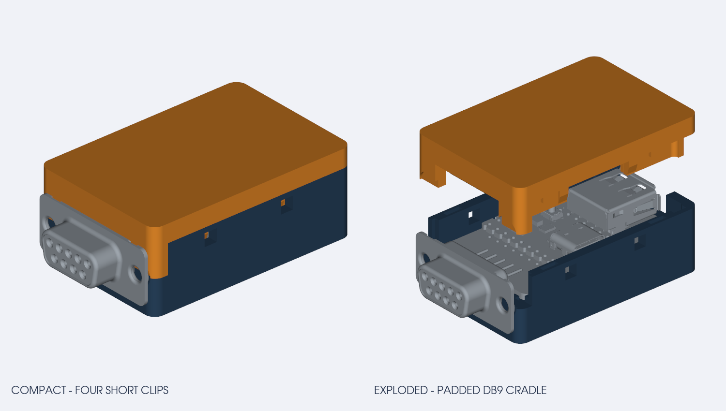
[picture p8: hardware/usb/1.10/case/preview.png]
Compact assembled case and exploded view


## Files

| File | Purpose |
| --- | --- |
| [Base STL](retrolink-usb-1.10-base.stl) | Bottom half, outside face already on the bed. |
| [Lid STL](retrolink-usb-1.10-lid.stl) | Top half, outside face already on the bed. |
| [Case STEP](retrolink-usb-1.10-case.step) | Two assembled enclosure solids, without electronics or rubber pads. |
| [Generator](case.py) | CadQuery dimensions, exports, rendering and fit validation. |
| [Tests](test_case.py) | Thirteen geometry regressions. |
| [Dependencies](requirements.txt) | Pinned direct Python dependencies. |

Use the current base **and** lid together: they are not interchangeable with
earlier prototypes. The files above replace the experimental large M3 enclosure.
All dimensions are **millimetres**; slice at **100%**, without scaling.

## Compact dimensions and clip changes

| Feature | Current default |
| --- | --- |
| Case envelope, excluding connectors | **50.19 x 33.50 x 19.70 mm** |
| First prototype envelope | 50.00 x 33.50 x 19.70 mm |
| Main PCB | 43 x 28 x 1.6 mm, 2 mm corner radius |
| Wall / roof / floor thickness | 2.4 mm, except local pad recesses |
| Clip count | Four, two per long side |
| Total individual clip length, including root | 14.7 / 14.1 mm |
| Spring beam section | 1.2 mm thick x **4.8 mm tall** |
| Root blend | **1.2 mm concave radius in the XY bending plane** |
| Hook insertion deflection / engagement | **0.20 mm** nominal |
| Hook retention lip height | **1.8 mm** |
| Receiver vertical allowance | 0.15 mm |
| Alignment-key clearance | 0.15 mm per mating face |
| PCB lengthwise allowance | **0.10 mm per end / 0.20 mm total nominal travel** |
| PCB side-to-side / vertical allowance | 0.35 mm per side / 0.20 mm |
| USB-A opening | 17.4 x 8.5 mm; bottom raised 1 mm, top unchanged |
| USB-C side wall | Closed; internal socket clearance retained |

Dedicated stops at both PCB ends reduce the previous 0.70 mm modeled lengthwise
travel without changing the outer dimensions, clip fit or lateral guides. They
contact straight board edges rather than the rounded corners. If the real print
is still loose or too tight, adjust `--board-end-clearance`, not the shell size.
The 0.20 mm target is nominal CAD travel, not a guarantee of printer accuracy.

Compared with the first short-clip prototype, the beams are 50% taller, the hook
lips are deeper, and nominal closing deflection falls from 0.30 to 0.20 mm.
The roots now blend in the **actual bending direction** and extend to the roof,
rather than relying on a fillet in the perpendicular plane. Lead-in ramps ease
closing, internal stops limit accidental over-pressing, and four independent
alignment tongues limit sliding between the halves.

A conservative rectangular-beam screen gives approximately **0.78% strain**,
including 0.15 mm print error, versus approximately 1.02% for the first design.
This is not FEA, a PLA material qualification or proof of strength. Thicker hooks
and larger engagement alone would increase closing force, so do not enlarge them
indiscriminately.

## DB9 support without obstructing the mating face

The **entire flange and mounting holes remain outside the case**. The plastic
stops 0.20 mm behind the modeled rear flange plane; nothing projects in front of
the flange, and there are no screws through its mounting holes. This avoids the
front lip that would obstruct the computer's connector.

A reinforced rear cradle contains two shallow pad recesses against the flat
top and bottom of the **metal backshell**, not against its pins or the PCB.
Fit **two soft, nonconductive rubber or silicone strips, each 2 x 12 x 1 mm**:

- Use soft solid material, approximately Shore A 20-30, not hard plastic, metal
  shims or multiple layers of tape.
- Pad locations are x=44.9..46.9, y=8..20 in the assembly coordinate system.
  The 12 mm direction runs across the DB9 shell.
- Each pad has a nominal **24 mm2 metal contact area**. Its seated thickness is
  0.80 mm when the seam is fully closed: 20% nominal compression.
- Clip take-up can reduce compression; the 0.15 mm receiver allowance must not
  be confused with zero-play screw clamping. Rubber compliance and printer
  tolerances affect the actual preload.
- The recess locates the pad. If adhesive is needed to hold it during assembly,
  keep the **total pad-plus-adhesive thickness at 1 mm**.

Intended extraction load path: **case -> cradle -> rubber friction -> DB9 metal
shell**. The closer PCB end stops are locating features, not connector strain
relief; they can engage before the rear flange backing. This is **not positive
flange capture**: without sufficient pad grip,
the connector can slip and the solder joints can still be loaded. Do not claim
complete strain relief without a physical retention test.

Dry-fit the case **without pads first**. Then add the pads and verify that the
case still closes gently and stays closed. If the pads force the lid open or make
closing substantially harder, stop; use softer material or reduce the modeled
preload. Do not force the clips against an oversized/hard pad.

## PLA printing and assembly

- 0.4 mm nozzle, 0.20 mm layers; four perimeters, five top/bottom layers and
  25-35% infill are starting settings.
- Keep both STLs in the supplied orientations. The beam length runs along
  printed layers. Do not stand the lid on an edge.
- **Use local supports beneath all four horizontal clip arms.** Supports must
  be allowed to start on part surfaces, not only on the build plate. Start with
  a removable 0.20 mm interface gap and inspect the slicer preview.
- The receiver openings are approximately 3.1 mm wide and should normally
  bridge without support. Check your printer's capability.
- Remove support completely from roots, ramps, hooks and locator pockets.
  Use ordinary PLA rather than brittle silk/filled PLA; avoid hot environments.
- Do not scale the whole model to correct fit. Adjust clearances in the source
  or through the CLI and check elephant-foot compensation.

1. Unplug all cables. Dry-fit the two empty halves and gently test each clip.
   All four hooks should engage without a hard squeeze. Never bend a clip outward.
2. Open the case and lower the PCB onto the four support lands, with the DB9
   flange outside. The lower front seam allows the rear metal collars to drop in.
3. Confirm clearance around the diode, solder tails and the module. Fit the two
   rubber pads only after the unpadded fit is correct.
4. Align the stepped DB9 end and locator tongues. Press locally near each clip,
   not hard on the center of the roof. Check all four receiver windows.
5. With the adapter disconnected, verify that the metal DB9 shell cannot slide
   axially inside the case under a gentle hand load. Then test fit on an
   unpowered spare connector before use on the computer. Stop if there is motion.
6. To open, press one hook inward through its window with a blunt plastic tool,
   lift that corner only enough to release it, and repeat. Do not lever the lid
   against still-engaged hooks or push beyond the internal stops.

These clips are for occasional servicing, not repeated flexing.
For programming, disconnect the adapter from the MSX and USB devices, release
the lid, and lift the PCB out of the base as needed for USB-C cable access.

## Source geometry and assumptions

The design uses the [revision 1.10 PCB](../retrolink.kicad_pcb) and its supplied
[STEP models](../libraries/), not screenshot measurements.

- Origin: KiCad X=102.15, Y=102.25 mm, with exported +Y toward USB-C and z=0 at
  the main PCB underside. The enclosure checks the nominal 1.6 mm PCB thickness,
  not just the approximately 1.51 mm exported substrate.
- The module is an **RP2040 Zero**, not a Raspberry Pi Zero SBC. Its modeled
  substrate spans z=3.504..4.595 mm.
- The USB-C envelope is x=19.970..29.550, y=19.511..27.041,
  z=3.685..7.845 mm. It is enclosed with clearance behind the solid side wall.
- The DB9 flat metal pad lands are z=-4.815 and z=6.005 mm; the flange rear face
  is x=47.640 mm. Different connector models need a new fit review.
- The underside keepout reserves 3.2 mm for solder and leads. Header sockets,
  alternate modules and oversized cable overmoulds may require adjustments.

## Regeneration and adjustments

The [MD 1.10 case](../../../md/1.10/case/README.md) reuses this generator's
shell, short clips and export helpers with different connector openings and
support placement. USB defaults and printable geometry are unchanged by this
shared-code extraction.

Python 3.13 was used. From this folder in PowerShell:

```powershell
python -m venv .venv
.\.venv\Scripts\python.exe -m pip install -r requirements.txt
.\.venv\Scripts\python.exe case.py
.\.venv\Scripts\python.exe -m unittest discover -s . -p test_case.py -v
```

The generator overwrites the two STLs, STEP and preview. Use `--output` for
trial settings:

```powershell
.\.venv\Scripts\python.exe case.py --output .\trial --key-clearance 0.20 --hook-engagement 0.15
.\.venv\Scripts\python.exe case.py --output .\board-fit --board-end-clearance 0.05
.\.venv\Scripts\python.exe case.py --output .\softer-clamp --pad-compression 0.10
.\.venv\Scripts\python.exe case.py --output .\raised-module --module-lift 2.0
```

| Option | Range and effect |
| --- | --- |
| `--fit-clearance` | 0.25-0.55 mm shell and PCB side clearance; changes wall position, not the dedicated end stops. |
| `--board-end-clearance` | 0.05-0.20 mm at each PCB end; total nominal lengthwise travel is twice this value. |
| `--key-clearance` | 0.12-0.25 mm locator fit; independent of the clips. |
| `--hook-engagement` | 0.15-0.25 mm; smaller eases closing but reduces retention. |
| `--pad-compression` | 0.10-0.20 mm per 1 mm pad; smaller eases closing but reduces grip. |
| `--flange-clearance` | 0.15-0.25 mm between the rear flange and case backing face. |
| `--module-lift` | 0-6 mm added to the supplied module height; raises the roof for internal clearance. |

To validate the supplied assembly, export a temporary STEP using KiCad 10:

```powershell
$assembly = Join-Path $env:TEMP 'retrolink-usb-1.10-fit.step'
& 'C:\Program Files\KiCad\10.0\bin\kicad-cli.exe' pcb export step `
    --force --user-origin '102.15x102.25mm' --output $assembly ..\retrolink.kicad_pcb
.\.venv\Scripts\python.exe case.py --assembly $assembly
Remove-Item $assembly
```

This rejects unexpected assembly bounds and cannot be combined with
`--module-lift`. The preview includes electronics when an assembly is supplied;
the print files and case STEP always contain **only the two plastic halves**.

Digital checks cover valid connected solids, nominal PCB and component clearance,
sampled PCB/lid insertion, four hook catches and receiver release clearances,
alignment keys, over-travel stops, pad backing and metal-only contact, solder
keepouts, bounded lengthwise PCB travel even at maximum vertical take-up, a solid
USB-C side wall, parameter limits, watertight meshes at bed z=0 and a two-solid STEP
round-trip. Pad compression and inward clip offsets are geometric checks, not
rubber/PLA deformation simulations. Physical closure, durability and retention
tests remain necessary.

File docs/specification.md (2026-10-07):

# The Retro Hacker RetroLink Specification

## Version

RetroLink specification version: `1.00`

Firmware version: `1.00`

Hardware revision: `1.00`

This document defines the initial hardware and firmware-facing specification for RetroLink USB, a USB HID adapter that connects modern USB joysticks and USB mice to classic MSX computers through the standard DB9 joystick port. It does not specify the separate RetroLink MD variant; see the [MD wiring and firmware guide](../software/md/README.md).

## Goals

- Use an RP2040 Zero module as the first hardware platform.
- Provide a USB-A host connector for USB HID joystick and mouse devices.
- Present MSX-compatible joystick and mouse signals through a DB9 connector.
- Keep the firmware architecture compatible with the Raspberry Pi Pico SDK and TinyUSB where practical.
- Keep USB firmware source code under `software/usb/` (joystick firmware in `software/usb/joystick/`, mouse firmware in `software/usb/mouse/`) and generated UF2 artifacts under `firmware/usb/`.
- Avoid direct 5 V exposure on RP2040 GPIO pins.
- Keep connector assignments and electrical assumptions documented from the first revision.

## Known Hardware Baseline

The first RetroLink hardware revision is based on an RP2040 Zero board using the Raspberry Pi RP2040 microcontroller.

Known board features:

- USB-C connector on the RP2040 Zero board.
- 5 V, GND, and 3.3 V power pins.
- Exposed GPIO pins: GPIO 0, 1, 2, 3, 4, 5, 6, 7, 8, 9, 10, 11, 12, 13, 14, 15, 26, 27, 28, and 29.
- Boot and Reset buttons.

## Current PCB And Assembly Files

Hardware revision `1.00` now includes a [KiCad schematic](../hardware/usb/1.00/retrolink.kicad_sch), [PCB layout](../hardware/usb/1.00/retrolink.kicad_pcb), [interactive BOM](../hardware/usb/1.00/bom/ibom.html), and [production outputs](../hardware/usb/1.00/production). The [README PCB previews](../README.md#pcb-preview) now show the latest hardware revision `1.10` in top and bottom 3D renders, not photographs of tested hardware. Open the iBOM HTML locally in a browser; GitHub's file view does not run the interactive page.

The [exported BOM](../hardware/usb/1.00/production/bom.csv) currently lists one each of RZ1 (RP2040 Zero), J1 (DE9 socket), J2 (USB-A receptacle), and D1 (value `1N5819`, footprint `D_SOD-123`). The [README component table](../README.md#pcb-components) records quantities, footprints, and replaceable AliExpress search links. These are sourcing placeholders, not approved parts or verified stock.

The current export does not include the specified BSS138 channels, 10 kOhm pull-ups, USB data-line passives/ESD protection, or a separate VBUS current limiter. Their requirements below remain design requirements, not claims about the existing PCB implementation. Resolve these gaps and review schematic-to-PCB connectivity before manufacture or connection to an MSX; RP2040 GPIOs are not 5 V tolerant.

D1 requires package reconciliation: a common axial DO-41 1N5819 does not fit the SOD-123 footprint. Confirm the exact SMD part number, polarity, ratings, and forward-voltage behavior, then synchronize the schematic value, PCB, and BOM. J1 currently uses `DSUB-9_Socket_EdgeMount_P2.77mm`; J2 uses `TE_6364372-2`. Verify connector mating and mechanical dimensions against the intended MSX and selected parts. File availability does not establish ERC/DRC, assembly, or electrical validation. Regenerate the iBOM and production exports after hardware changes.

## Design Assumptions

- The RP2040 Zero USB-C connector remains available for programming, bootloader access, and development, but the installed RetroLink adapter is powered from the MSX DB9 connector.
- The external USB-A connector is used as the USB host port for the attached joystick or mouse.
- RP2040 GPIO pins are 3.3 V logic and are not 5 V tolerant.
- The MSX joystick port may expose 5 V logic or 5 V pull-ups; therefore, DB9 signal interfaces must protect the RP2040.
- DB9 pin assignments follow the MSX General Purpose port convention unless later hardware documentation proves a different target requirement. Reference: [General Purpose port - MSX Wiki](https://www.msx.org/wiki/General_Purpose_port).
- Hardware revision `1.00` requires BSS138 MOSFET level shifters with 10 kOhm pull-up resistors for DB9 signals that cross between the RP2040 3.3 V domain and the MSX 5 V domain; these parts are not present in the current exported BOM.
- DB9 pin 5 supplies the board 5 V rail for hardware revision `1.00` through a series 1N5819 Schottky diode; the usable current budget from the MSX port and the post-diode voltage still need validation on representative machines.
- Firmware version `1.00` assumes the common RP2040 Zero onboard WS2812-compatible status LED is connected to GPIO 16. Validate this for the exact RP2040 Zero board variant before freezing the build.
- USB host VBUS current requirements for connected devices are not yet validated. Current limiting and measurement access remain requirements to address before hardware release.

Any assumption above must be revisited when electrical measurements, MSX model compatibility notes, or board revision documents are added.

## Recommended Connector Strategy

### USB-C On RP2040 Zero

Keep the RP2040 Zero USB-C connector dedicated to development, programming, bootloader access, and firmware debug over USB CDC for hardware revision `1.00`.

The installed adapter power source is DB9 pin 5 from the MSX port. The PCB must include a series 1N5819 Schottky diode from DB9 pin 5 to the board 5 V rail so MSX power can feed RetroLink, but RP2040 Zero USB-C power cannot backfeed the MSX port during programming.

Do not wire the external USB-A data pins in parallel with the RP2040 Zero USB-C data pins. Sharing USB data lines between two physical connectors would create ambiguous host/device roles and can make programming, enumeration, and electrical behavior unreliable.

### USB-A Host Connector

Use the external USB-A female connector as the HID host port.

Recommended hardware revision `1.00` approach:

- Use RP2040 PIO-based USB host signaling for the USB-A D+ and D- lines.
- Reserve adjacent GPIO pins for the USB data pair.
- Use the Raspberry Pi Pico SDK as the base firmware SDK.
- Use TinyUSB host APIs where practical, with the USB transport layer isolated so the project can adapt if the final implementation uses a TinyUSB-supported host backend or a PIO USB integration layer.

Recommended USB-A wiring:

| USB-A pin | Signal | Recommended connection | Notes |
| --- | --- | --- | --- |
| 1 | VBUS +5 V | Post-diode DB9-derived board 5 V through a current-limited high-side switch or resettable fuse | Current budget and voltage after diode drop must be validated against the MSX port and expected USB HID devices. |
| 2 | D- | GPIO 3 through USB routing network | Keep paired with D+ and route as a short differential pair. |
| 3 | D+ | GPIO 2 through USB routing network | GPIO 2 is the recommended PIO USB D+ assignment for hardware revision `1.00`. |
| 4 | GND | Board ground | Must share ground with RP2040 Zero and DB9 ground. |
| Shield | Shield | Chassis/shield strategy to be defined by PCB design | Do not assume shield should be tied directly to logic ground without EMC review. |

Recommended USB support components:

- Series resistors on D+ and D- near the RP2040-side driver pins, with values selected according to the chosen PIO USB reference design.
- USB ESD protection on D+ and D- close to the USB-A connector.
- 15 kOhm pull-down resistors on D+ and D- if required by the selected USB host implementation/reference design.
- Current-limited 5 V VBUS switch or resettable fuse for USB-A pin 1.
- Optional VBUS enable and fault signals connected to spare GPIO pins if a power switch with control/status is used.

Recommended optional VBUS control mapping:

| Function | Recommended GPIO | Direction | Notes |
| --- | --- | --- | --- |
| USB host D+ | GPIO 2 | USB data | Reserved for PIO USB host. |
| USB host D- | GPIO 3 | USB data | Reserved for PIO USB host. |
| USB VBUS enable | GPIO 4 | Output | Optional; only if the power switch supports enable control. |
| USB VBUS fault | GPIO 5 | Input | Optional; only if the power switch exposes fault status. Use 3.3 V-compatible signaling. |

## Recommended DB9 Connector Wiring

The current PCB uses a DE9 female socket with the `DSUB-9_Socket_EdgeMount_P2.77mm` footprint, superseding the earlier male-connector recommendation in this document. This describes the existing hardware files, not a firmware pin-assignment change. Verify mating compatibility, connector orientation, and pin numbering against the intended MSX before ordering or assembly.

Standard MSX joystick-port signal convention for hardware revision `1.00`:

| DB9 pin | MSX signal | RetroLink direction | Recommended GPIO | Electrical interface requirement |
| --- | --- | --- | --- | --- |
| 1 | Up | Output to MSX | GPIO 6 | BSS138 level shifter with 10 kOhm pull-ups. |
| 2 | Down | Output to MSX | GPIO 7 | BSS138 level shifter with 10 kOhm pull-ups. |
| 3 | Left | Output to MSX | GPIO 8 | BSS138 level shifter with 10 kOhm pull-ups. |
| 4 | Right | Output to MSX | GPIO 9 | BSS138 level shifter with 10 kOhm pull-ups. |
| 5 | +5 V from MSX port | Primary board power input | GPIO 13 optional through BSS138 or divider | Feed the board 5 V rail through a series 1N5819 diode and input protection; do not connect directly to RP2040 GPIO. |
| 6 | Trigger A | Output to MSX | GPIO 10 | BSS138 level shifter with 10 kOhm pull-ups. |
| 7 | Trigger B | Output to MSX | GPIO 11 | BSS138 level shifter with 10 kOhm pull-ups. |
| 8 | OUT / strobe from MSX | Input to RetroLink | GPIO 12 | BSS138 level shifter with 10 kOhm pull-ups. |
| 9 | GND | Ground reference | GND | Common ground with RP2040 Zero and USB-A ground. |

### Level Shifting Standard

Hardware revision `1.00` requires a BSS138 bidirectional MOSFET level-shifter circuit with 10 kOhm pull-up resistors for DB9-side signals that cross between the RP2040 and MSX voltage domains. The current four-component PCB BOM does not implement these channels.

Recommended circuit per shifted signal:

- BSS138 source connected to the RP2040 3.3 V side.
- BSS138 drain connected to the MSX 5 V side.
- BSS138 gate connected to 3.3 V.
- 10 kOhm pull-up from the RP2040 side to 3.3 V.
- 10 kOhm pull-up from the MSX side to 5 V.
- Common ground between RP2040 Zero, USB-A, and DB9.

This circuit is appropriate for the active-low, open-drain style DB9 signaling model used by RetroLink. Firmware should drive an asserted signal low and release the GPIO for the inactive state; it should not drive the shifted DB9 lines high as push-pull outputs.

The BSS138 and 10 kOhm values must still be validated against MSX mouse and joystick timing requirements. If rise time is too slow for a future timing-sensitive mode, the resistor value or buffer topology may need to change in a later hardware revision.

### DB9 Output Interface

The DB9 output signals should behave as active-low switch closures from the MSX perspective. The RP2040 must not drive a DB9 signal high at 5 V.

Recommended implementation:

- Use one BSS138 level-shifter channel per DB9 output signal.
- Use 10 kOhm pull-ups on both the 3.3 V and 5 V sides of each BSS138 channel.
- Drive the interface active only when the emulated joystick or mouse signal should pull the MSX line low.
- Release the interface for the inactive state.

This maps cleanly to firmware as logical active-low outputs and avoids exposing RP2040 GPIO pins to 5 V.

### DB9 Pin 8 Input

Treat DB9 pin 8 as an MSX-driven signal for hardware revision `1.00`.

Recommended implementation:

- Use one BSS138 level-shifter channel with 10 kOhm pull-ups before GPIO 12.
- Add input protection appropriate for the selected circuit.
- Keep the firmware abstraction independent from the physical GPIO so mouse or joystick timing behavior can be implemented without hard-coding board details.

### DB9 Pin 5 Power Handling

Treat DB9 pin 5 as the primary 5 V power input for the installed RetroLink adapter in hardware revision `1.00`.

Recommended implementation:

- Route DB9 pin 5 to the board 5 V rail through a series 1N5819 Schottky diode, with the diode anode on DB9 pin 5 and the cathode on the RetroLink board 5 V rail.
- Validate that the 1N5819 forward-voltage drop still leaves enough voltage for the RP2040 Zero and attached USB HID devices across the expected MSX port current range.
- Place additional input protection, such as a resettable fuse or current-limited power switch, as required by the final power budget.
- Use the series diode to prevent USB-C development power from backfeeding the MSX port when the RP2040 Zero is connected to USB-C for programming.
- Prevent MSX-derived power from backfeeding a connected USB-C host if the RP2040 Zero board power path does not already guarantee that behavior.
- Feed USB-A VBUS from the post-diode DB9-derived 5 V rail through its own current-limited switch or resettable fuse.
- Keep the RP2040 GPIO domain at 3.3 V and use BSS138 level shifting for DB9 logic signals.
- Validate the available MSX port current budget before selecting the USB-A VBUS current limit.

If DB9 +5 V sensing is needed in firmware, connect the sense input only through a high-impedance divider, BSS138 logic-level path, or other 3.3 V-compatible sensing circuit.

For hardware revision `1.00`, a BSS138 channel may be used for a logic-level presence sense only if the resulting signal behavior is validated. Do not use the BSS138 path to draw board power from DB9 pin 5.

## Firmware Architecture Implications

USB firmware source code lives under `software/usb/`: the joystick firmware in `software/usb/joystick/` and the mouse firmware in `software/usb/mouse/`. Both target the same USB hardware. Generated USB UF2 files live under `firmware/usb/` as `retrolink-joystick-<version>.uf2` and `retrolink-mouse-<version>.uf2`.

The wiring above should be reflected in firmware as board-level configuration, not scattered GPIO constants.

Recommended firmware modules:

| Module | Responsibility |
| --- | --- |
| `platform` | RP2040 Zero board initialization, GPIO mapping, clocks, timers, and board revision constants. |
| `usb_host` | USB host initialization, enumeration, connection state, and TinyUSB or PIO USB integration. |
| `hid` | HID report parsing for joysticks and mice. |
| `msx_port` | Active-low DB9 signal model, pin 8 input handling, and timing-sensitive MSX behavior. |
| `mapping` | Translation from HID joystick/mouse events to MSX joystick or mouse signals. |
| `config` | Build-time or runtime configuration for board revision and device behavior. |
| `diagnostics` | Optional debug state, fault reporting, and validation hooks. |

Firmware version `1.00` provides USB-C CDC debug and descriptor-based USB HID joystick/gamepad translation. The current source drives up/down/left/right on GPIO0/2/4/6 (DB9 pins 1/2/3/4); button usages 1/2 drive A/B on GPIO1/3 (DB9 pins 6/7). This requires updated wiring rather than the original hardware revision `1.00` assignments above. Absolute X/Y axes, four/eight-way hats, and discrete D-pad usages are supported. Outputs assert low and release to high impedance through the documented level shifters. The first report is decoded directly, without neutral calibration. Axis thresholds are below 25% and above 75% of the descriptor's logical range, with the middle 50% neutral. Opposing directions cancel. GPIO5 / DB9 pin 8 is reserved for the MSX OUT/strobe input and is neither initialized, read, nor driven in this joystick mode. The unused GPIO4/5 USB VBUS control/fault reservations have been removed; those circuits must not share the MSX pins.

States are combined across report IDs and interfaces. Detach, invalid reports, or failed receive requests release the affected interface's state; a receive-request failure requires reconnection. CDC reports mapping support and state changes, and the GPIO16 LED pulses on newly asserted controls. Vendor-specific protocols are not implemented, and the joystick firmware does not handle mice. See [software behavior and tests](../software/usb/joystick/README.md#current-behavior) for decoder limits, public interfaces, and host-test commands. Compilation and simulated tests do not replace validation with the actual joystick and MSX hardware.

USB mouse firmware version `1.00` runs on the same hardware revision `1.10` pin assignments and implements the standard MSX mouse protocol. GPIO5 / DB9 pin 8 is read as the MSX strobe. Each edge presents the next nibble of the signed 8-bit X and Y offsets on DB9 pins 1-4 (GPIO0/2/4/6), high nibble first, with positive X meaning left and positive Y meaning up. The left and right buttons drive DB9 pins 6/7 (GPIO1/3). The alternate BIOS read cycle reports zero, so the BIOS detects a mouse rather than a trackball. A 1.5 ms gap between strobe edges restarts the sequence. A dedicated RP2040 core polls pin 8 and updates the outputs from RAM. Holding the left button while the mouse connects selects joystick emulation. See the [mouse firmware guide](../software/usb/mouse/README.md#current-behavior) for supported mice, scaling, and tests; the timing still requires validation on physical MSX machines.

Original firmware constants for hardware revision `1.00` (historical wiring, not the current source mapping; see the [current GPIO table](../software/usb/joystick/README.md#current-behavior)):

| Constant | Value |
| --- | --- |
| `RETROLINK_FW_VERSION` | `1.00` |
| `RETROLINK_HW_REVISION` | `1.00` |
| `USB_HOST_DP_GPIO` | `2` |
| `USB_HOST_DM_GPIO` | `3` |
| `USB_HOST_VBUS_EN_GPIO` | `4` if fitted, otherwise disabled |
| `USB_HOST_VBUS_FAULT_GPIO` | `5` if fitted, otherwise disabled |
| `MSX_UP_GPIO` | `6` |
| `MSX_DOWN_GPIO` | `7` |
| `MSX_LEFT_GPIO` | `8` |
| `MSX_RIGHT_GPIO` | `9` |
| `MSX_TRIGGER_A_GPIO` | `10`, active-low output to DB9 pin 6 |
| `MSX_TRIGGER_B_GPIO` | `11` |
| `MSX_OUT_STROBE_GPIO` | `12` |
| `MSX_5V_SENSE_GPIO` | `13` if fitted, otherwise disabled |
| `RETROLINK_STATUS_LED_GPIO` | `16`, assuming the common RP2040 Zero onboard WS2812-compatible LED |

## Firmware Build

The USB joystick firmware uses the Raspberry Pi Pico SDK build system from `software/usb/joystick/`; the mouse firmware uses the same system from `software/usb/mouse/`.

Expected build commands from the repository root:

```powershell
git submodule update --init --recursive
make -C software/usb/joystick
make -C software/usb/mouse
```

The Makefile supplies Pico SDK, toolchain, and Pico-PIO-USB paths. See [software build instructions](../software/usb/joystick/README.md#build) for prerequisites and overrides on other machines.

The builds are configured to copy their UF2 artifacts to:

```text
firmware/usb/retrolink-joystick-<version>.uf2
firmware/usb/retrolink-mouse-<version>.uf2
```

The current firmware uses TinyUSB device CDC on native USB root port 0, TinyUSB host on Pico-PIO-USB root port 1, and a 120 MHz system clock. The current source configures GPIO27 (D+) and GPIO28 (D-) and requires updated USB-A and MSX wiring. The hardware revision `1.00` tables above retain the original wiring; the current build is not compatible with that wiring. See the [software compatibility notes](../software/usb/joystick/README.md#current-behavior).

## Reserved GPIO Pins

Leave GPIO 0, 1, 14, 15, 26, 27, 28, and 29 unassigned in hardware revision `1.00` unless a later schematic needs them.

This reservation describes the original hardware revision only. The current source uses GPIO0/1 for MSX up/button A and GPIO27/28 for USB-A D+/D-; UART stdio is disabled and must remain off those MSX pins.

Potential future uses:

- UART diagnostics.
- Board revision detection.
- Configuration buttons or DIP switches.
- Status LEDs.
- Analog measurements on ADC-capable pins.
- Second DB9 port support if the project scope expands.

## Validation Required Before Hardware Release

Before freezing hardware revision `1.00`, validate and document:

- Reconciliation of the current four-component PCB/BOM with the required level shifting, pull-ups, USB protection, and VBUS current limiting.
- D1's exact SOD-123-compatible part number and J1/J2 connector mating, mounting geometry, and pin numbering.
- Schematic ERC, PCB DRC, and synchronization of the PCB, iBOM, production BOM, and fabrication outputs.
- USB host implementation choice and exact required D+/D- passive components.
- Pico SDK/TinyUSB host build using the selected PIO USB host configuration.
- RP2040 Zero status LED GPIO and WS2812 timing on the exact board variant.
- USB-A VBUS current limit and power source behavior.
- MSX DB9 pin 5 current budget on representative machines.
- 1N5819 orientation, forward-voltage drop, and current rating for DB9 pin 5 power input.
- Power-path isolation between DB9 pin 5, RP2040 Zero USB-C 5 V, and USB-A VBUS.
- Whether the DB9-derived 5 V rail can safely power the RP2040 Zero and expected USB HID devices.
- DB9 voltage levels on representative MSX machines.
- Required DB9 output pull-up behavior for joystick and mouse modes.
- BSS138 plus 10 kOhm rise times for joystick and MSX mouse timing.
- Pin 8 timing and voltage behavior for MSX mouse support.
- Grounding and shield strategy.
- ESD protection selection for USB-A and DB9 external connectors.
- Firmware timing requirements for active-low DB9 outputs.

## Open Questions

- Which exact SOD-123 diode and connector listings will be qualified for the current footprints?
- How will the missing level-shifting and USB protection requirements be incorporated into the PCB before release?
- Is GPIO 16 correct for the onboard status LED on the exact RP2040 Zero board variant used in production?
- What maximum USB device current should RetroLink support?
- What current limit should be used for USB-A VBUS when the board is powered from MSX DB9 pin 5?
- Does the selected 1N5819 diode preserve enough post-diode voltage for the board and USB-A device across the validated MSX port current budget?
- Which MSX mouse protocol timing requirements must be supported beyond the implemented BIOS-compatible baseline (1.5 ms strobe timeout, zeroed alternate cycle), for example the 2014 extended protocol or trackball emulation?
- Should hardware revision `1.00` support one DB9 port only, or reserve mechanical and GPIO space for a second port?

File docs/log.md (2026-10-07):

# RetroLink Version Change Log

## Software and Firmware

### USB

#### Mouse Firmware v1.00 - 2026-10-07

- Added the USB mouse firmware in `software/usb/mouse/` for USB hardware revision `1.10`, exporting `retrolink-mouse-1.00.uf2` alongside the joystick UF2s in `firmware/usb/`.
- Implemented the MSX mouse protocol: GPIO5/DB9 pin 8 strobe edges select signed X/Y nibbles on GPIO0/2/4/6, with a 1.5 ms resync timeout and a zeroed alternate cycle; left/right buttons drive GPIO1/3.
- Added core 1 RAM-resident strobe handling, boot and report-descriptor mouse decoding, movement scaling with carry, left-button joystick emulation, CDC diagnostics, and native regression tests; physical MSX validation remains pending.

#### Joystick Firmware v1.10 - 2026-10-06

- Moved the joystick source to `software/usb/joystick/` and renamed the joystick UF2s to `retrolink-joystick-<version>.uf2` on 2026-10-07; release contents are unchanged and the Makefile now generates the new name.
- Set the build firmware and hardware identifiers to `1.10`, matching USB hardware revision `1.10` GPIO assignments, and exported `retrolink-1.10.uf2`; the Makefile now passes its version to CMake.
- Added a tested USB joystick list to `firmware/README.md`; Hyperkin Trooper 2, Dazz Dual Shock, a generic USB Super Nintendo clone, and Datafrog Wireless work with firmware `1.10` on hardware revision `1.10`, while an Xbox One controller does not.

#### Joystick Firmware v1.00 - 2026-09-20

- Defined initial firmware-facing module boundaries and GPIO constants for the future RP2040 Zero implementation.
- Set the initial firmware and specification version to `1.00`.
- Added the initial Pico SDK/TinyUSB host firmware scaffold under `software/`, with UF2 export configured under `firmware/`.
- Added a `software/Makefile` wrapper that builds the versioned UF2 artifact into `firmware/`.
- Updated `software/Makefile` to use Pico SDK-managed CMake, Ninja, Python, and SDK paths by default on Windows.
- Added Pico-PIO-USB as a repo-managed submodule and linked it into the firmware build for GPIO-based USB host support.
- Enabled USB-C CDC debug logging while keeping the USB-A connector as the Pico-PIO-USB HID host port.
- Replaced activity-based mapping with descriptor-decoded directions and buttons A/B on GPIO6-11, with high-impedance release and host regression tests.
- Reassigned USB-A host D+/D- from GPIO2/GPIO3 to GPIO27/GPIO28; the current build requires matching updated wiring instead of the original hardware revision `1.00` data pair.
- Remapped MSX up/A/down/B/left/OUT/right to GPIO0/1/2/3/4/5/6 and removed unused GPIO4/5 VBUS reservations; updated wiring is required and OUT remains unused in joystick mode.

### MD

#### Firmware v1.10 - 2026-10-06

- Bumped MD firmware and hardware identifiers to `1.10` and exported `retrolink-md-1.10.uf2`; GPIO assignments match MD hardware revision `1.10` unchanged, and the Makefile now passes its version to CMake.
- Added raw TH-phase D0..D5 samples and the MSX pin 8 common level to USB-C CDC diagnostics, with 1 s status heartbeats.
- Added a tested MegaDrive joystick list to `firmware/README.md`; the 8BitDo M30 with Mega Drive adapter works with firmware `1.10` on hardware revision `1.10`.
- Pointed the MD build's shared LED and `joystick.h` sources to `software/usb/joystick/` after the USB source split on 2026-10-07; MD firmware behavior is unchanged.

#### Firmware v1.00 - 2026-09-23

- Added the separate MD firmware for 3-/6-button Mega Drive pads, using D0..D5 on GPIO28/26/14/12/27/13 and TH on GPIO15, with B/C mapped to MSX A/B.
- Added MD common-line-aware MSX low/release outputs on GPIO0/2/4/6/1/3, CDC diagnostics, LED activity, invalid-frame release, native regression tests, and a versioned MD UF2 build.
- Disabled the MD build's B0/B1 USB enumeration workaround to keep GPIO15 dedicated to SELECT; older-chip USB hub compatibility is limited.

## Hardware

### USB

#### Hardware revision 1.10 - 2026-09-23

- Raised the USB case's USB-A opening bottom by 1 mm, reducing its height to 8.5 mm without changing its top, width or the MD case.
- Shared the USB case geometry and export helpers with the MD enclosure while preserving USB default dimensions and geometry.
- Added dedicated case end stops targeting 0.20 mm total nominal PCB lengthwise play and closed the USB-C side opening; programming now requires opening the case.
- Revised the compact case with four short radiused-root clips, alignment keys, over-travel stops and a low-preload padded DB9 metal cradle, keeping the flange exposed; physical strength and retention remain unvalidated.
- Added a two-piece PLA snap-fit enclosure prototype with USB-A/DB9/USB-C access, parametric CAD, printable STLs, and geometry checks; physical fit and clip strength remain unvalidated.
- Identified `1.10` as the latest USB hardware revision and replaced the README previews with updated angled, top, and bottom 3D renders.

#### Hardware revision 1.00 - 2026-09-20

- Documented the initial RP2040 Zero hardware baseline, USB-A host wiring, MSX DB9 wiring, and BSS138 level shifting guidance.
- Changed the power architecture so DB9 pin 5 supplies the board 5 V rail with protected USB-C and USB-A power paths.
- Selected a 1N5819 Schottky diode from DB9 pin 5 to the board 5 V rail to prevent USB-C programming power from backfeeding the MSX port.
- Created the initial KiCad schematic/project for hardware revision `1.00` without creating a PCB layout.
- Documented the current PCB layout, preview renders, iBOM, and four-part sourcing table, including unresolved protection and package requirements.

### MD

#### Hardware revision 1.10 - 2026-10-06

- Extended the MD case 4 mm toward the male DB9 and mirrored the female-end profile to remove the incorrect-model through-passages; male-connector fit requires physical validation.
- Connected the isolated RP2040 Zero GND pad to MSX pin 9 and MD pin 8 with a B.Cu track from J1.9 and a via into the RP2040 ground pour; earlier boards need a GND wire, as they work only while USB-C supplies ground. Regenerate the production outputs.
- Added a dual-DB9 four-clip PLA enclosure matching the USB case's 50.19 x 33.50 x 19.70 mm size, with tight PCB end stops, enclosed USB-C and padded MSX-side support; physical validation remains pending.

#### Hardware revision 1.00 - 2026-09-23

- Documented the MD DE9-to-DE9 board, updated controller GPIO assignments, and angled/front/back renders, with level conversion and electrical validation still required.

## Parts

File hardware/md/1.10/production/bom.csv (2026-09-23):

Designator | Footprint | Quantity | Value | LCSC Part #
D1 | D_SOD-123 | 1 | 1N5819
J1 | DSUB-9_Socket_EdgeMount_P2.77mm | 1 | DE9_Socket
J2 | DSUB-9_Pins_EdgeMount_P2.77mm | 1 | DE9_Pins
RZ1 | RP2040-Zero | 1 | RP2040-Zero

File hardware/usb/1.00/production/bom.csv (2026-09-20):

Designator | Footprint | Quantity | Value | LCSC Part #
D1 | D_SOD-123 | 1 | 1N5819
J1 | DSUB-9_Socket_EdgeMount_P2.77mm | 1 | DE9_Socket
J2 | TE_6364372-2 | 1 | USB_A
RZ1 | RP2040-Zero | 1 | RP2040-Zero

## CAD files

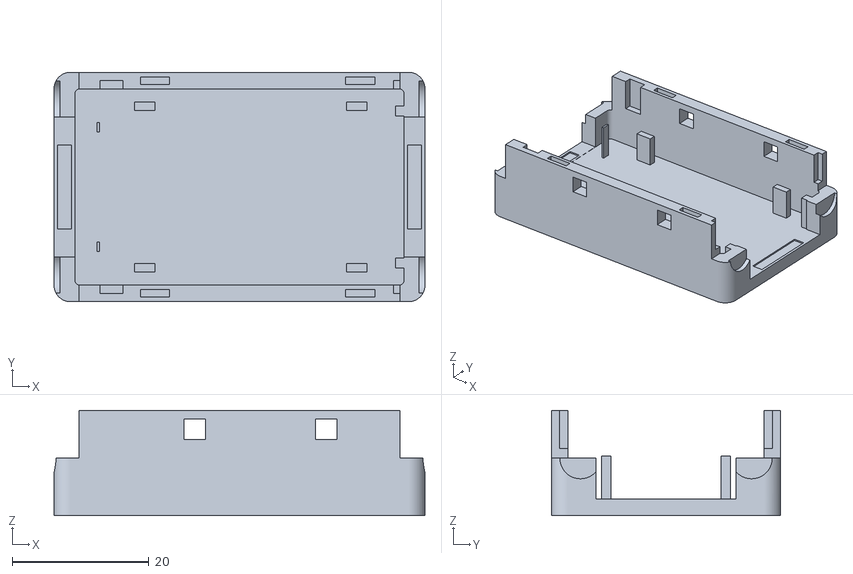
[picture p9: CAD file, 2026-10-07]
hardware/md/1.10/case/retrolink-md-1.10-base.stl
54.2 x 33.5 x 15.4

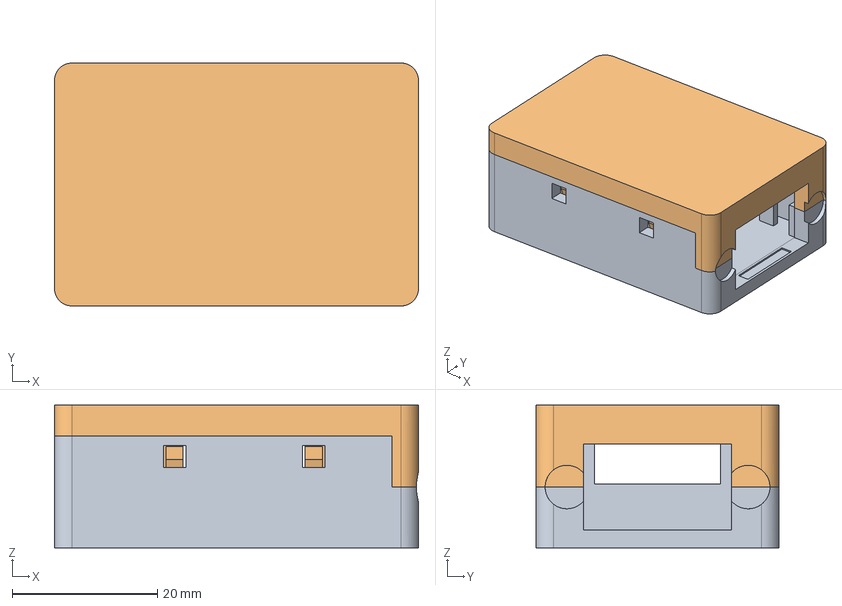
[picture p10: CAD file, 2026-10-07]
hardware/usb/1.10/case/retrolink-usb-1.10-case.step
50.2 x 33.5 x 19.7 mm

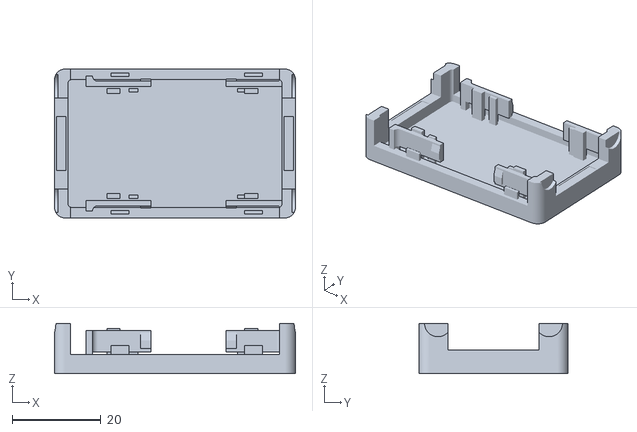
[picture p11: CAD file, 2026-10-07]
hardware/md/1.10/case/retrolink-md-1.10-lid.stl
54.2 x 33.5 x 11.3

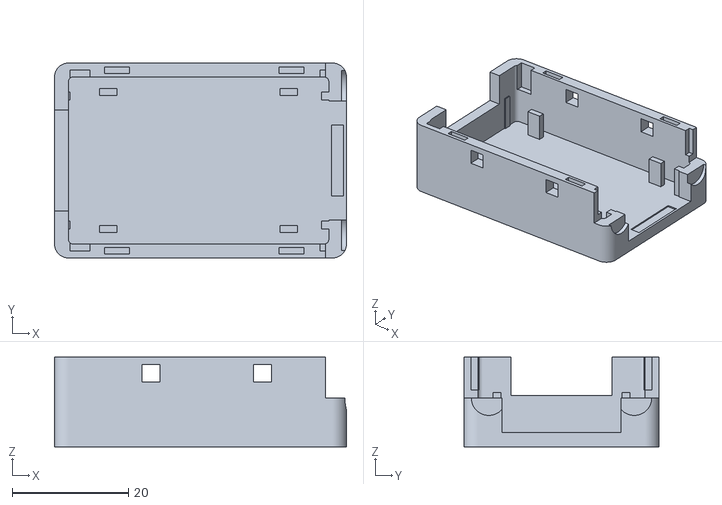
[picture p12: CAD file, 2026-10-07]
hardware/usb/1.10/case/retrolink-usb-1.10-base.stl
50.2 x 33.5 x 15.4

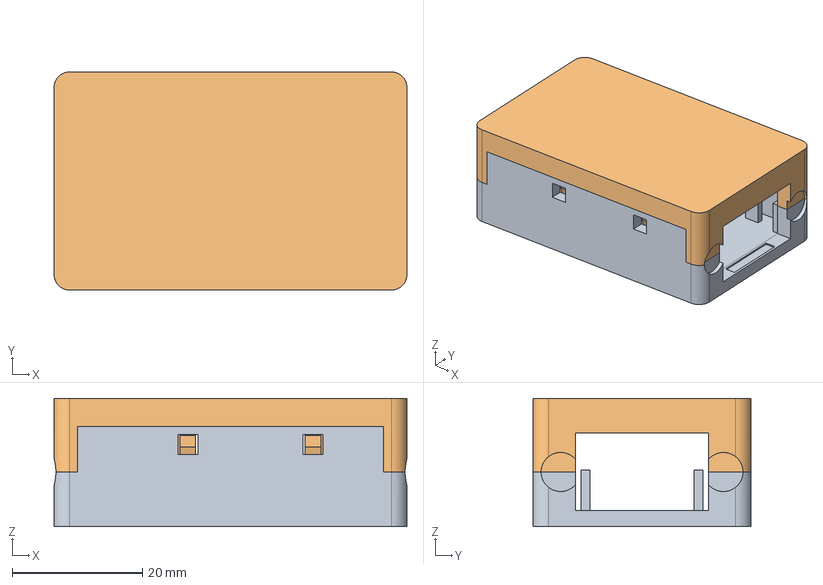
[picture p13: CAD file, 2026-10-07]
hardware/md/1.10/case/retrolink-md-1.10-case.step
54.2 x 33.5 x 19.7 mm

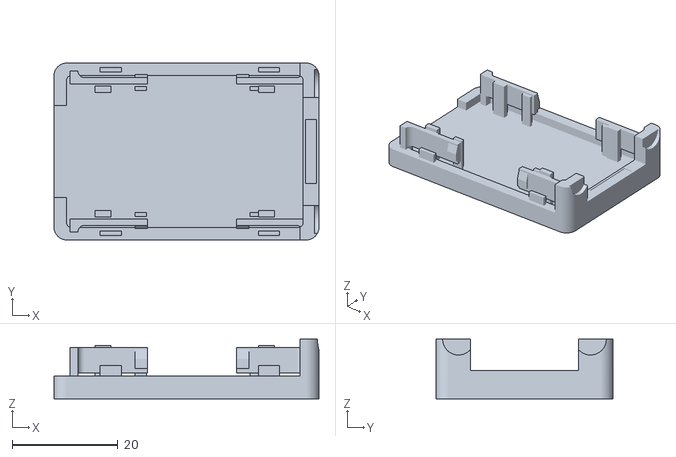
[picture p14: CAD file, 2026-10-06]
hardware/usb/1.10/case/retrolink-usb-1.10-lid.stl
50.2 x 33.5 x 11.3

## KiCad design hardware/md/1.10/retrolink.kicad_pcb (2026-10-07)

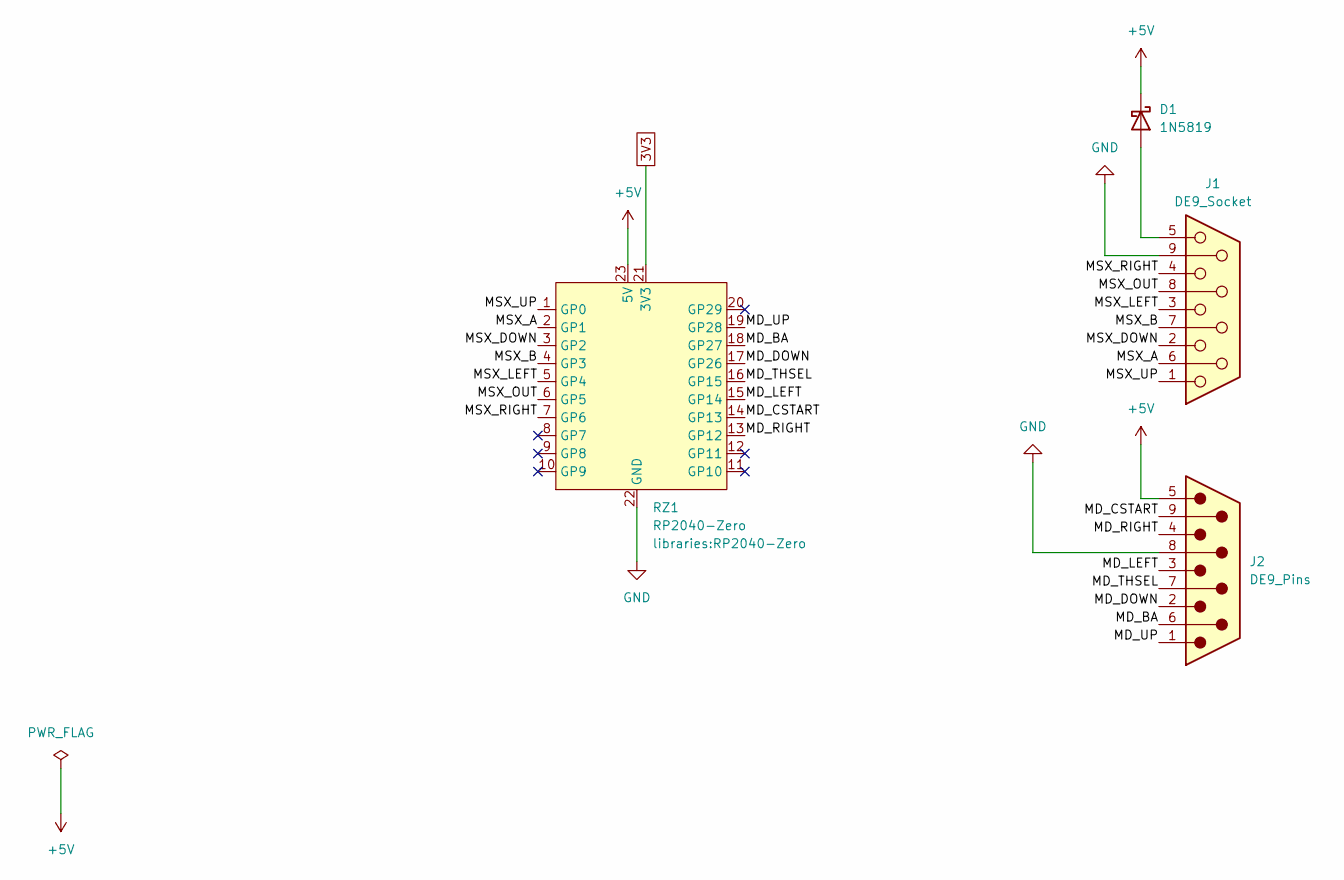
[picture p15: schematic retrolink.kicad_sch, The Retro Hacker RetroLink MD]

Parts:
D1: 1N5819; D_SOD-123
J1: DE9_Socket; DSUB-9_Socket_EdgeMount_P2.77mm
J2: DE9_Pins; DSUB-9_Pins_EdgeMount_P2.77mm
RZ1: RP2040-Zero

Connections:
3V3: RZ1.21 (3V3)
+5V: D1.1 (K), J2.5, RZ1.23 (5V)
/MD_BA: J2.6, RZ1.18 (GP27)
/MD_CSTART: J2.9, RZ1.14 (GP13)
/MD_DOWN: J2.2, RZ1.17 (GP26)
/MD_LEFT: J2.3, RZ1.15 (GP14)
/MD_RIGHT: J2.4, RZ1.13 (GP12)
/MD_THSEL: J2.7, RZ1.16 (GP15)
/MD_UP: J2.1, RZ1.19 (GP28)
/MSX_A: J1.6, RZ1.2 (GP1)
/MSX_B: J1.7, RZ1.4 (GP3)
/MSX_DOWN: J1.2, RZ1.3 (GP2)
/MSX_LEFT: J1.3, RZ1.5 (GP4)
/MSX_OUT: J1.8, RZ1.6 (GP5)
/MSX_RIGHT: J1.4, RZ1.7 (GP6)
/MSX_UP: J1.1, RZ1.1 (GP0)
GND: J1.9, J2.8, RZ1.22 (GND)
unnamed: D1.2 (A), J1.5

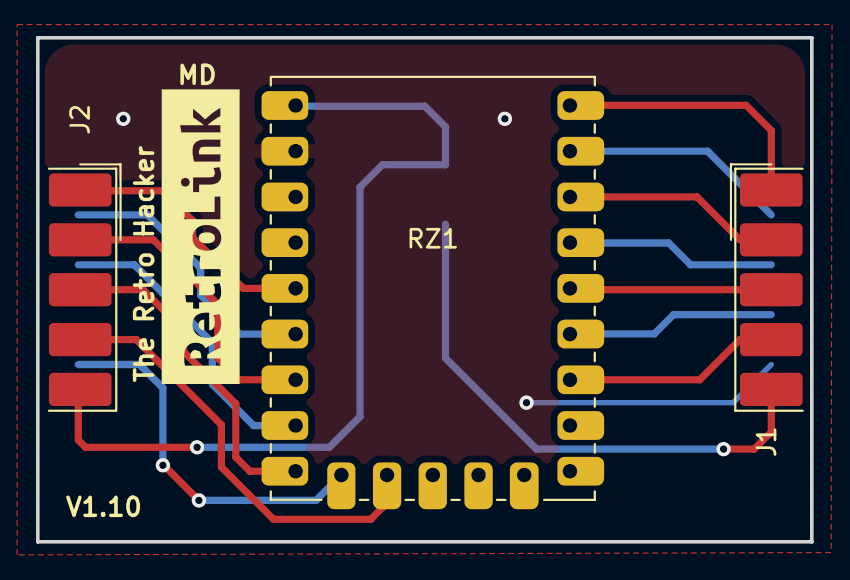
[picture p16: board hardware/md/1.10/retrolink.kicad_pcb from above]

Board: 2 copper layers, 43.0 x 28.0 mm, 5 parts (1 on the bottom side), 17 nets.

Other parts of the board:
kibuzzard-6AB06415: G***; kibuzzard-6AB06415

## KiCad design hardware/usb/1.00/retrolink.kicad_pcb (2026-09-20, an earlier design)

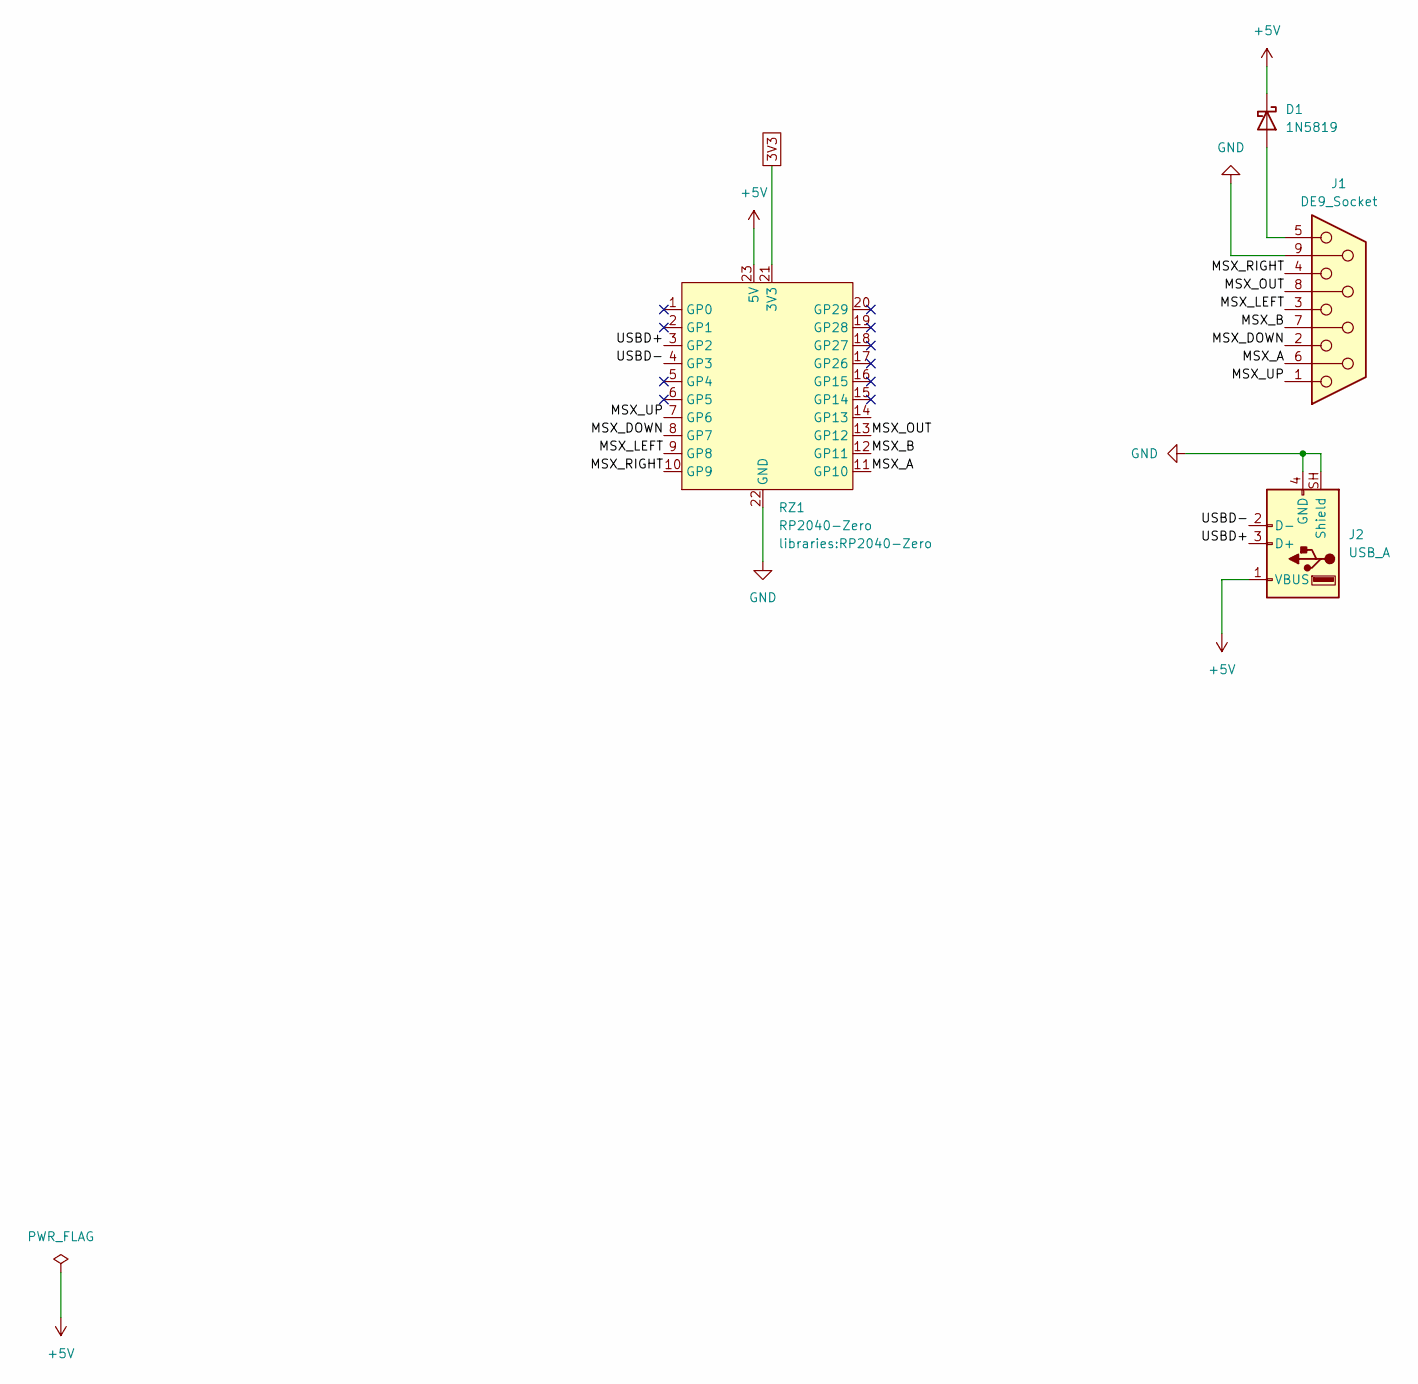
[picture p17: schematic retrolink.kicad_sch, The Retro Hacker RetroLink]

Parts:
D1: 1N5819; D_SOD-123
J1: DE9_Socket; DSUB-9_Socket_EdgeMount_P2.77mm
J2: USB_A; TE_6364372-2
RZ1: RP2040-Zero

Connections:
3V3: RZ1.21 (3V3)
+5V: D1.1 (K), J2.1 (VBUS), RZ1.23 (5V)
/MSX_A: J1.6, RZ1.11 (GP10)
/MSX_B: J1.7, RZ1.12 (GP11)
/MSX_DOWN: J1.2, RZ1.8 (GP7)
/MSX_LEFT: J1.3, RZ1.9 (GP8)
/MSX_OUT: J1.8, RZ1.13 (GP12)
/MSX_RIGHT: J1.4, RZ1.10 (GP9)
/MSX_UP: J1.1, RZ1.7 (GP6)
/USBD+: J2.3 (D+), RZ1.3 (GP2)
/USBD-: J2.2 (D-), RZ1.4 (GP3)
GND: J1.9, J2.4 (GND), J2.SH (Shield), RZ1.22 (GND)
unnamed: D1.2 (A), J1.5

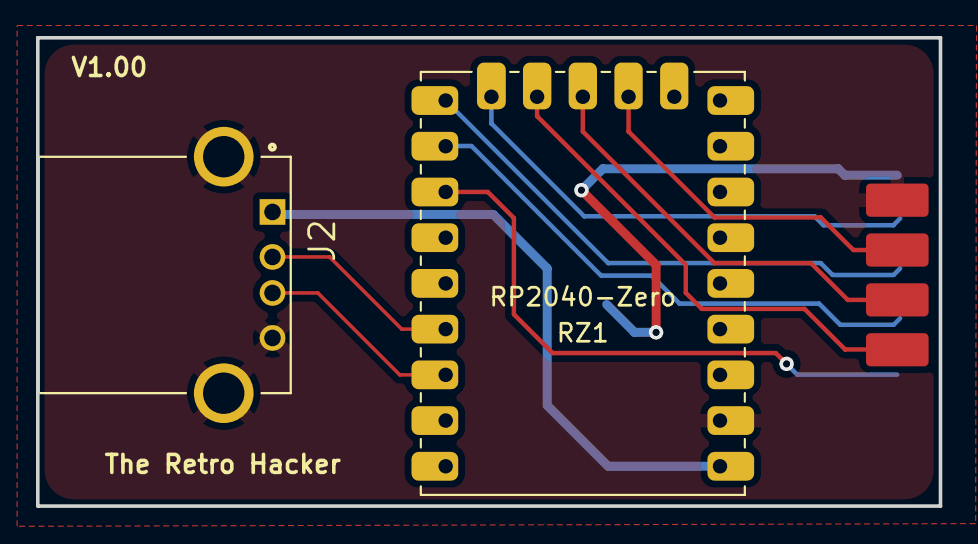
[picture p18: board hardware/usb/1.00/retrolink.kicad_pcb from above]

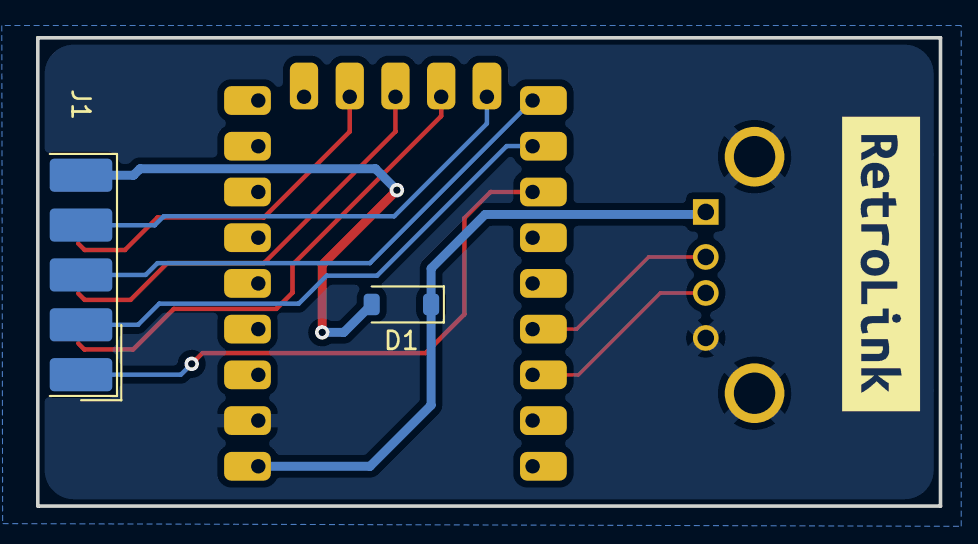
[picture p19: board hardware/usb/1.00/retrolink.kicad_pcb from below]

Board: 2 copper layers, 50.2 x 26.0 mm, 5 parts (3 on the bottom side), 12 nets.

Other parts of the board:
kibuzzard-6AB06415: G***; kibuzzard-6AB06415

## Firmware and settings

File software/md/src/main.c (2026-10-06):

#include <stdio.h>

#include "pico/stdlib.h"
#include "pico/stdio_usb.h"

#include "retrolink/board_config.h"
#include "retrolink/md_port.h"
#include "retrolink/msx_output.h"
#include "retrolink/status_led.h"

int main(void)
{
    msx_output_init();
    md_port_init();
    status_led_init();
    stdio_init_all();

    md_pad_state_t previous = {MD_PAD_NONE, 0};
    md_poll_result_t previous_result = MD_POLL_NO_PAD;
    md_pad_samples_t previous_raw = {0};
    bool previous_common = false;
    joystick_state_t previous_controls = 0;
    bool was_connected = false;
    uint32_t next_poll = time_us_32();
    uint32_t next_heartbeat = next_poll;
    uint32_t last_log = next_poll;

    while (true) {
        if ((int32_t)(time_us_32() - next_poll) >= 0) {
            md_pad_state_t state;
            md_poll_result_t result = md_port_poll(&state);
            md_pad_samples_t raw = md_port_last_samples();
            bool common_high = msx_output_common_high();
            joystick_state_t controls = md_pad_to_msx(state);
            msx_output_set_state(controls);
            if ((controls & (joystick_state_t)~previous_controls) != 0) {
                status_led_pulse();
            }
            bool connected = stdio_usb_connected();
            if (connected && !was_connected) {
                printf("RetroLink MD firmware %s, hardware %s\r\n",
                       RETROLINK_FW_VERSION, RETROLINK_HW_REVISION);
                printf("MD D0..D5 GPIO28,26,14,12,27,13; TH GPIO15; B->MSX A, C->MSX B\r\n");
                printf("raw=idle/1stLow/3rdLow/3rdHigh/4thLow D0..D5 bits (1=high); no pad reads 3f; "
                       "3-button idle pad reads 3f/33/33/3f/33; common=MSX pin 8 (1 releases outputs)\r\n");
            }
            bool decoded_changed = result != previous_result || state.type != previous.type ||
                                   state.buttons != previous.buttons || common_high != previous_common;
            bool raw_changed = raw.idle_high != previous_raw.idle_high ||
                               raw.first_low != previous_raw.first_low ||
                               raw.third_low != previous_raw.third_low ||
                               raw.third_high != previous_raw.third_high ||
                               raw.fourth_low != previous_raw.fourth_low;
            uint32_t now = time_us_32();
            /* Floating inputs can change every poll; rate-limit raw-only changes. */
            if (connected && (!was_connected || decoded_changed ||
                              (raw_changed && (uint32_t)(now - last_log) >= 100000u) ||
                              (int32_t)(now - next_heartbeat) >= 0)) {
                printf("MD result=%u (0=ok,1=absent/invalid,2=timing) pad=%u (0=none,1=3btn,2=6btn) buttons=%03x "
                       "raw=%02x/%02x/%02x/%02x/%02x common=%u MSX=%02x\r\n",
                       (unsigned)result, (unsigned)state.type, (unsigned)state.buttons,
                       raw.idle_high, raw.first_low, raw.third_low, raw.third_high, raw.fourth_low,
                       (unsigned)common_high, (unsigned)controls);
                last_log = now;
                next_heartbeat = now + 1000000u;
            }
            was_connected = connected;
            previous = state;
            previous_result = result;
            previous_raw = raw;
            previous_common = common_high;
            previous_controls = controls;
            /* Schedule from completion so delayed diagnostics cannot shorten TH reset time. */
            next_poll = time_us_32() + RETROLINK_MD_POLL_US;
        }
        status_led_task();
        tight_loop_contents();
    }
}

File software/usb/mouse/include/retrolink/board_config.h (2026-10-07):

#ifndef RETROLINK_BOARD_CONFIG_H
#define RETROLINK_BOARD_CONFIG_H

#include <stdint.h>

#define RETROLINK_SPEC_VERSION "1.10"

#ifndef RETROLINK_FW_VERSION
#define RETROLINK_FW_VERSION "1.00"
#endif

#ifndef RETROLINK_HW_REVISION
#define RETROLINK_HW_REVISION "1.10"
#endif

#define RETROLINK_USB_HOST_DP_GPIO 27u
#define RETROLINK_USB_HOST_DM_GPIO 28u

#define RETROLINK_MSX_UP_GPIO 0u
#define RETROLINK_MSX_DOWN_GPIO 2u
#define RETROLINK_MSX_LEFT_GPIO 4u
#define RETROLINK_MSX_RIGHT_GPIO 6u
#define RETROLINK_MSX_TRIGGER_A_GPIO 1u
#define RETROLINK_MSX_TRIGGER_B_GPIO 3u
#define RETROLINK_MSX_OUT_STROBE_GPIO 5u

#define RETROLINK_STATUS_LED_GPIO 16u
#define RETROLINK_STATUS_LED_PULSE_MS 80u

#define RETROLINK_SYS_CLOCK_KHZ 120000u

#define RETROLINK_DEBUG_CDC_HEARTBEAT_MS 2000u
#define RETROLINK_DEBUG_CDC_INPUT_NAME "USB HID mouse"

/* A strobe edge arriving later than this after the previous edge restarts the X/Y nibble sequence. */
#ifndef RETROLINK_MOUSE_STROBE_TIMEOUT_US
#define RETROLINK_MOUSE_STROBE_TIMEOUT_US 1500u
#endif

/* USB mouse counts per MSX mouse count; raise it to slow the pointer down. */
#ifndef RETROLINK_MOUSE_DIVISOR
#define RETROLINK_MOUSE_DIVISOR 2
#endif

/* Joystick emulation: holding the left button in the first report after mounting selects it. */
#define RETROLINK_MOUSE_JOYSTICK_SELECT_MS 1000u
#define RETROLINK_MOUSE_JOYSTICK_SAMPLE_MS 20u
#define RETROLINK_MOUSE_JOYSTICK_THRESHOLD 2

#endif

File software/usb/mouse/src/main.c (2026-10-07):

#include "hardware/clocks.h"
#include "pico/stdlib.h"
#include "tusb.h"

#include "retrolink/board_config.h"
#include "retrolink/debug_cdc.h"
#include "retrolink/mouse_port.h"
#include "retrolink/status_led.h"
#include "retrolink/usb_host.h"

int main(void)
{
    set_sys_clock_khz(RETROLINK_SYS_CLOCK_KHZ, true);

    status_led_init();
    debug_cdc_init();
    mouse_port_init();
    usb_host_init();

    debug_cdc_log("RetroLink mouse firmware %s, hardware %s\r\n", RETROLINK_FW_VERSION, RETROLINK_HW_REVISION);
    debug_cdc_log("USB-C CDC debug active; USB-A host on GPIO%u/GPIO%u\r\n", RETROLINK_USB_HOST_DP_GPIO, RETROLINK_USB_HOST_DM_GPIO);

    while (true) {
        tud_task();
        tuh_task();
        debug_cdc_task();
        usb_host_task();
        status_led_task();
        tight_loop_contents();
    }
}

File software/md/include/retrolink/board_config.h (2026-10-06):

#ifndef RETROLINK_BOARD_CONFIG_H
#define RETROLINK_BOARD_CONFIG_H

#define RETROLINK_HW_REVISION "1.10"

#define RETROLINK_MD_UP_GPIO 28u
#define RETROLINK_MD_BA_GPIO 27u
#define RETROLINK_MD_DOWN_GPIO 26u
#define RETROLINK_MD_THSEL_GPIO 15u
#define RETROLINK_MD_LEFT_GPIO 14u
#define RETROLINK_MD_CSTART_GPIO 13u
#define RETROLINK_MD_RIGHT_GPIO 12u

#define RETROLINK_MSX_UP_GPIO 0u
#define RETROLINK_MSX_TRIGGER_A_GPIO 1u
#define RETROLINK_MSX_DOWN_GPIO 2u
#define RETROLINK_MSX_TRIGGER_B_GPIO 3u
#define RETROLINK_MSX_LEFT_GPIO 4u
#define RETROLINK_MSX_OUT_STROBE_GPIO 5u
#define RETROLINK_MSX_RIGHT_GPIO 6u

#define RETROLINK_STATUS_LED_GPIO 16u
#define RETROLINK_STATUS_LED_PULSE_MS 80u

#define RETROLINK_MD_SETTLE_US 10u
#define RETROLINK_MD_RESET_US 3000u
#define RETROLINK_MD_MAX_FRAME_US 500u
#define RETROLINK_MD_POLL_US 5000u

#endif

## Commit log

2026-08-01 Initial RetroLink hardware and firmware baseline
    - Add project documentation, specification, and version log
    - Define hardware revision 1.00 around RP2040 Zero, USB-A host, and MSX DB9
    - Add KiCad schematic/project for hardware revision 1.00
    - Add Pico SDK/TinyUSB firmware scaffold with Pico-PIO-USB submodule
    - Add Makefile build flow that generates firmware/retrolink-1.00.uf2
    - Add Copilot project instructions and version-log coordination rules
2026-08-01 - Enabled USB-C CDC debug logging while keeping the USB-A connector as the Pico-PIO-USB HID host port.
2026-09-20 - Replaced activity-based mapping with descriptor-decoded directions and buttons A/B on GPIO6-11, with high-impedance release and host regression tests.
    [retrolink.kicad_sch]
2026-09-23 Add USB host functionality and MSX joystick support
    - Implement main USB host application in main.c
    - Create msx_port.c for handling MSX joystick state and GPIO control
    - Add status_led.c for managing status LED behavior
    - Define TinyUSB configuration in tusb_config.h
    - Create USB descriptors in usb_descriptors.c for device identification
    - Implement USB host logic in usb_host.c to manage HID devices
    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
    [bom.csv, designators.csv, freerouting.dsn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]
2026-09-23 Update submodule path for Pico-PIO-USB and add new submodule reference
2026-09-23 Update README and Makefile for improved Pico SDK path handling and submodule reference
2026-09-23 - Reassigned USB-A host D+/D- from GPIO2/GPIO3 to GPIO27/GPIO28; the current build requires matching updated wiring instead of the original hardware revision `1.00` data pair. - Remapped MSX up/A/dow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
    [freerouting.dsn, retrolink.kicad_pcb, retrolink.kicad_sch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]
2026-09-23 Add RetroLink MD firmware and testing framework
    - Introduced CMakeLists.txt for building the RetroLink MD project with support for regression tests.
    - Created a Makefile for building the project on different platforms.
    - Added board configuration header defining GPIO mappings and hardware revision.
    - Implemented MD pad handling with md_pad.h and md_pad.c for decoding button states.
    - Developed md_port.h and md_port.c for interfacing with the MD port and reading input.
    - Created msx_output.h and msx_output.c for managing MSX joystick output.
    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
    [bom.csv, designators.csv, positions.csv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]
2026-10-06 Cases for both boards and adjusts to the md version
    [bom.csv, designators.csv, positions.csv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]
2026-10-06 Add lock files for KiCad PCB and project configurations
    - Created new lock files: ~retrolink.kicad_pcb.lck and ~retrolink.kicad_pro.lck
    - Lock files contain hostname and username information for session management
    [retrolink.kicad_pcb]
2026-10-06 Add diagnostics for raw D0..D5 samples and MSX pin 8 level in firmware
2026-10-07 hardware fix. v1.10 MD
    [retrolink.kicad_pcb]
2026-10-07 Refactor MD and USB case designs for improved fit and functionality
    - Updated the MD case dimensions to extend the plastic envelope by 4 mm toward the male DB9 connector, ensuring a better fit.
    - Modified the USB case to raise the USB-A opening by 1 mm, adjusting the dimensions accordingly.
    - Enhanced unit tests for both MD and USB cases to validate new dimensions and ensure compatibility.
    - Added new tests to check for proper exclusion of incorrect male models and to verify the mirroring of end profiles.
    - Updated README files to reflect changes in dimensions and functionality.
    - Adjusted STEP and STL files to align with the new design specifications.
    [retrolink-md-1.10-base.stl, retrolink-md-1.10-case.step, retrolink-md-1.10-lid.stl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]
2026-10-07 Add USB joystick support and related functionality
    - Implement USB host functionality for joystick input.
    - Add HID joystick parsing and decoding logic.
    - Introduce MSX port control for joystick state management.
    - Create debug CDC for logging and status reporting.
    - Implement status LED control for visual feedback.
    - Add USB descriptors for device identification.
    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
2026-10-07 Add USB mouse support and MSX mouse protocol implementation
    - Implement main firmware for USB mouse functionality in main.c.
    - Create mouse_port.c to handle MSX mouse port interactions, including GPIO management and motion tracking.
    - Add msx_mouse.c for MSX mouse protocol handling, including motion scaling and nibble reading.
    - Develop usb_host.c to manage USB host interactions, including HID mouse support and button state updates.
    - Introduce tests for HID mouse functionality in hid_mouse_test.c, covering various mouse descriptors and protocols.
    - Implement tests for MSX mouse protocol in msx_mouse_test.c, validating motion handling and joystick emulation.
2026-10-14 Add assembled board photos for RetroLink USB and MD variants
2026-10-14 Add new image for iOS device compatibility
2026-10-14 Refactor MD enclosure case dimensions and update tests
    - Adjusted the dimensions of the MD enclosure from 54.19 mm to 52.19 mm, shortening it by 1 mm at each DB9 end.
    - Updated unit tests to reflect the new dimensions and ensure validation checks are accurate.
    - Modified the README to describe the changes in the enclosure dimensions and the rationale behind them.
    - Enhanced the preview and export functions in the USB case code to accept optional pad shapes for better flexibility.
    - Updated binary files for the STL and images to reflect the latest design changes.
